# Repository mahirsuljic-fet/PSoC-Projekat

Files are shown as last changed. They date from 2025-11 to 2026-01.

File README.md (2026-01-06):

# PSoC-Projekat

#### [Seminarski rad](https://docs.google.com/document/d/1uanphD6yLatK8Oh72rCpiS6qyERxc_Ud)

## Projekat

### Dokumentacija
- #### [Documentacija projekta](./PSC_gr_6_dokumentacija.pdf)
- #### [Prezentacija projekta](./PSC_gr_6_prezentacija.pptx)

### Kod
- #### [Verilog](./verilog/)
- #### [Mobilna aplikacija](./RobotControlApp/)
- #### [Vcd2plot](./vcd2plot/)

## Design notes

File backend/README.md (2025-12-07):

# Flask backend 
Kako bi Kotlin aplikacija mogla jednostavno komunicirati sa backend-om potrebno je da backend uvijek bude dostupan na istom host-u i istom port-u.

RPi će od momenta boot-anja biti konfigurisan da aktivira svoj hotspot, a android aplikacija se direktno povezuje na tu mrežu.
RPi će imati static IP DHCP konfiguraciju tako da svaki put dobiva istu private IPv4 adresu, npr. 192.168.1.4.
Flask aplikaciji uvijek će biti dodijeljen port 5000.
Tako android aplikacija svaki request šalje na 192.168.1.4:5000/ + odgovarajući endpoint.

## Endpoints
Endpoint-i koje backend expose-a su sljedeći:
 + <code>/forward</code>
   + efektivno postavlja outpin pin na RPi na nivo HIGH, što FPGA dekodira kao kretanje unaprijed
 + <code>/backward</code>
   + efektivno postavlja output pin na RPi na nivo HIGH, što FPGA dekodira kao kretanje unazad
 + <code>/stop</code>
   + efektivno postavlja output pin na RPi na nivo HIGH, što FPGA dekodira kao zaustavljanje kretanja
 + <code>/left</code>
   + efektivno postavlja output pin na RPi na nivo HIGH, što FPGA dekodira kao kretanje lijevo
 + <code>/right</code>
   + efektivno postavlja output pin na RPi na nivo HIGH, što FPGA dekodira kao kretanje desno
 + <code>/</code>
   + index ili root path, ne radi ništa

## Startup
Kako ovaj backend servis treba da radi od samog starta, bit će kreiran sytemd servis koji će prilikom boot-a Raspbian sistema pokrenuti  i ovu Flask aplikaciju.

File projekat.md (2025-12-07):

# Opis projekta
Tema projekta je automobil koji se kontroliše putem mobilne aplikacije.
Automobil će imati 4 točka, 2 kočnice, parking senzore, LED svjetla, sposobnost detektovanja svjetla na semaforu, saobraćajnih znakova, prevenciju prelazka preko linije, itd.
Mobilna aplikacija će biti napisana u Kotlin programskom jeziku koristeći Android Studio i Jetpack Compose.
Komunikacija između mobilne aplikacije i Raspberry Pi će se odvijati putem HTTP protokola.
Komunikacija između Raspberry Pi i FPGA će se odvijati putem nekog serijskog transfer protokola (UART, I2C, SPI ili USB).

# Hardver sa tabelom ulaza i izlaza
| Upravljačke ploče | Slika |
| --- | ----- |
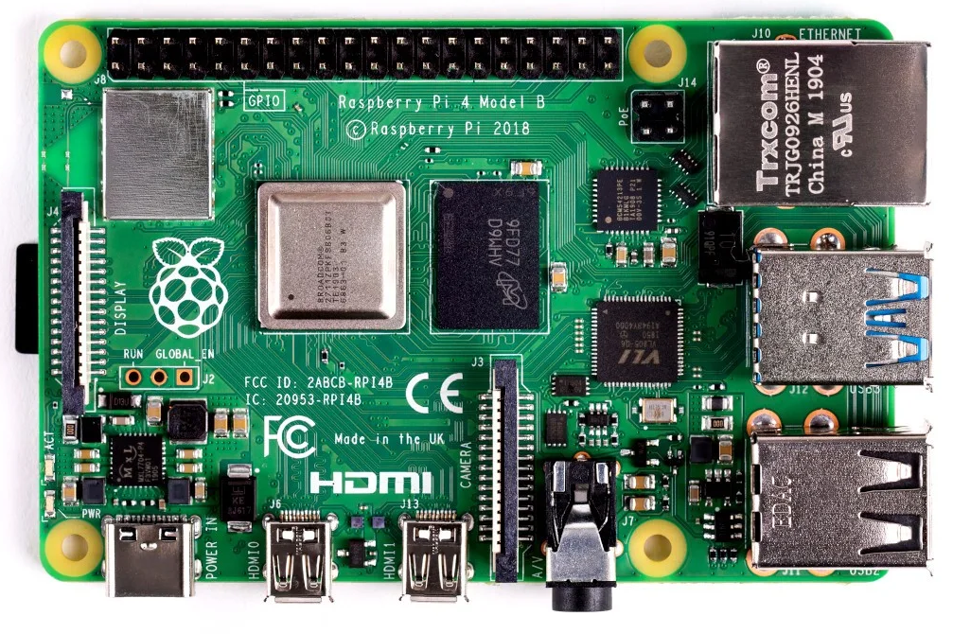
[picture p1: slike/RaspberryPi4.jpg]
| Raspberry Pi 4 |  |
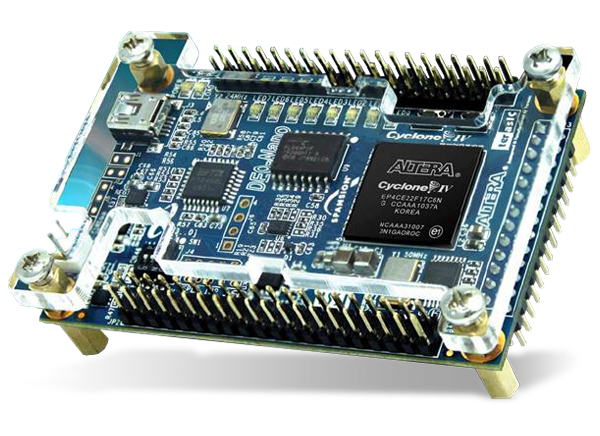
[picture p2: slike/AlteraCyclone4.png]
| Altera Cyclone 4 (FPGA) |  |
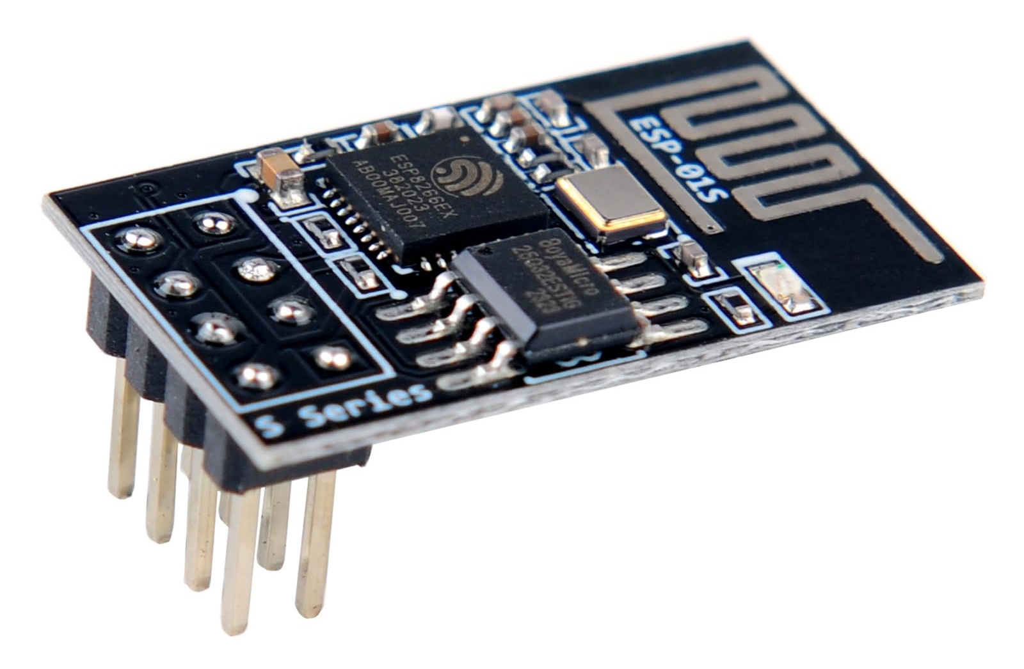
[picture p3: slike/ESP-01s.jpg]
| ESP-01s |  |

| Ulazi | Upravljačka ploča | Namjena | Slika |
| --- | --- | --- | ----- |
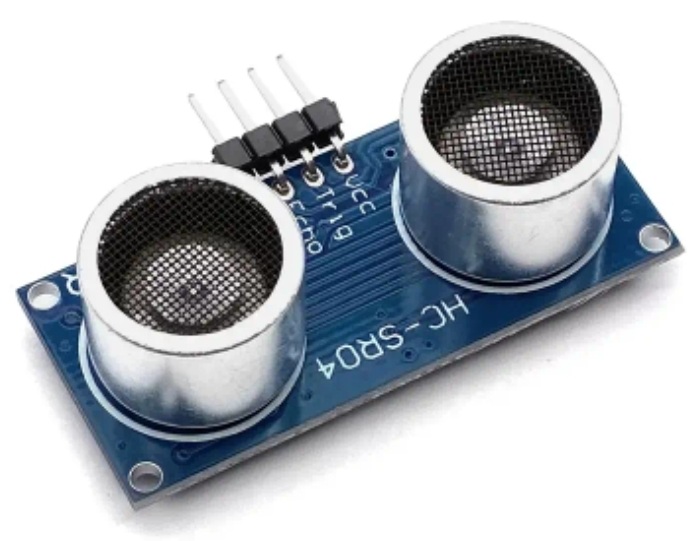
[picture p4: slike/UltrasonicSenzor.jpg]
| Ultrasonični senzor (HC-SR04P) x2 | FPGA | Parking senzori |  |
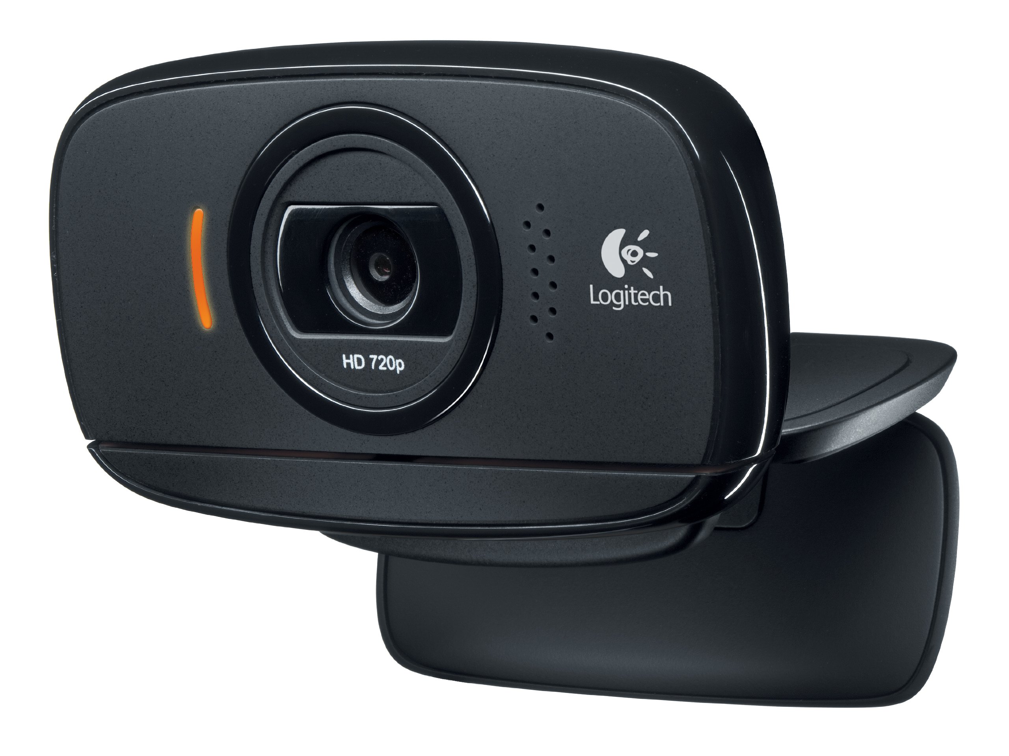
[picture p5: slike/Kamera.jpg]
| Kamera (Logitech C512) | Raspberry PI | Detekcija znakova i video stream |  |
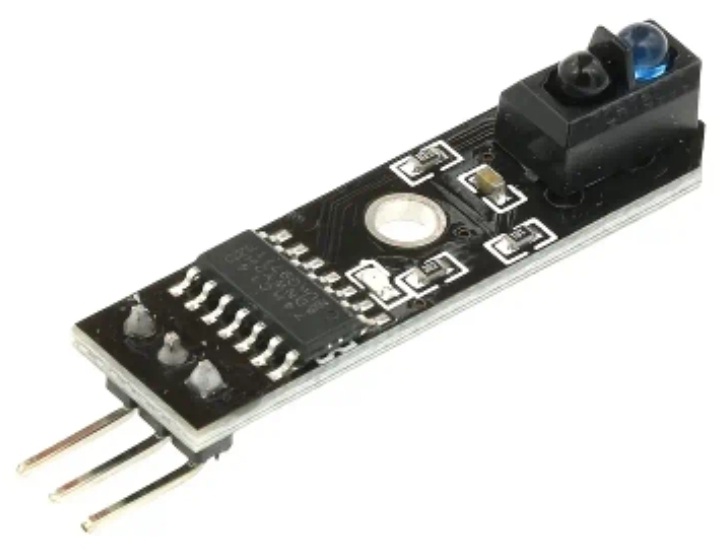
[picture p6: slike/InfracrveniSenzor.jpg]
| Infracrveni senzor x2 | FPGA | Detekcija linija |  |

| Izlazi | Upravljačka ploča | Namjena | Slika |
| --- | --- | --- | ----- |
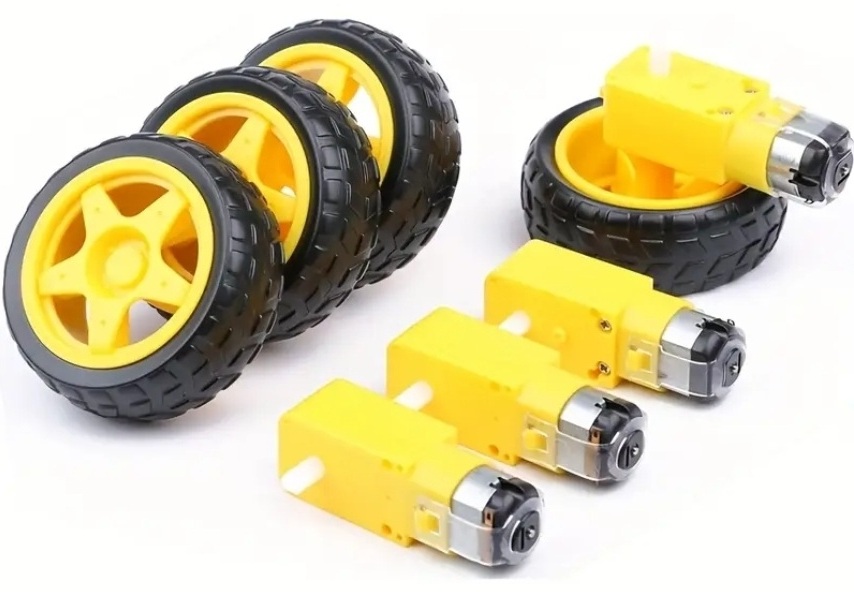
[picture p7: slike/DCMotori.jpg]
| DC motori x4 | FPGA | Kontrola kretanja |  |
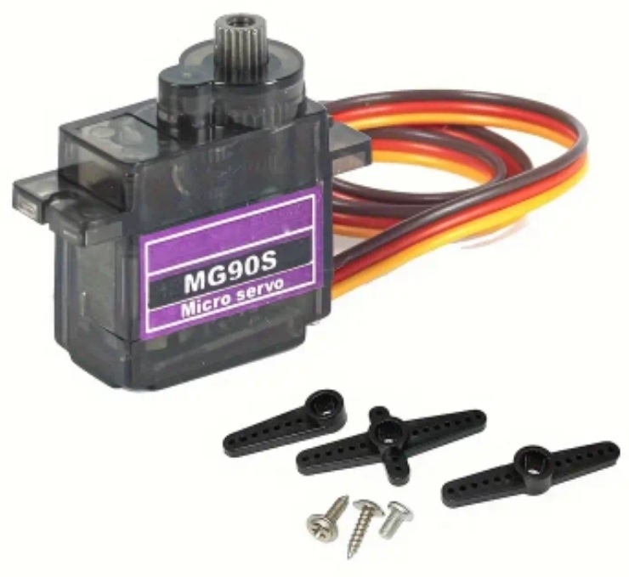
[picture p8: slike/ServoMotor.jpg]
| Servo motori x2 | FPGA | Kočnice |  |
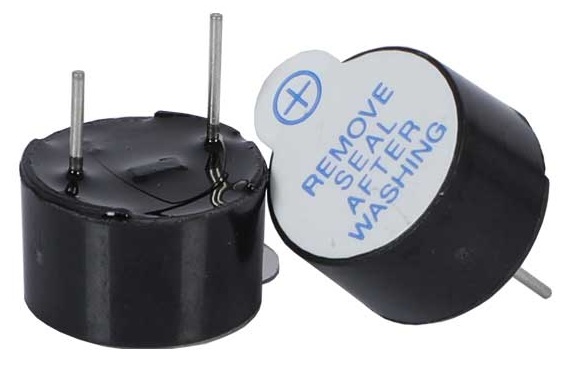
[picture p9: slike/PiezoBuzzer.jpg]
| Aktivni piezo buzzer | FPGA | Zvučna signalizacija |  |
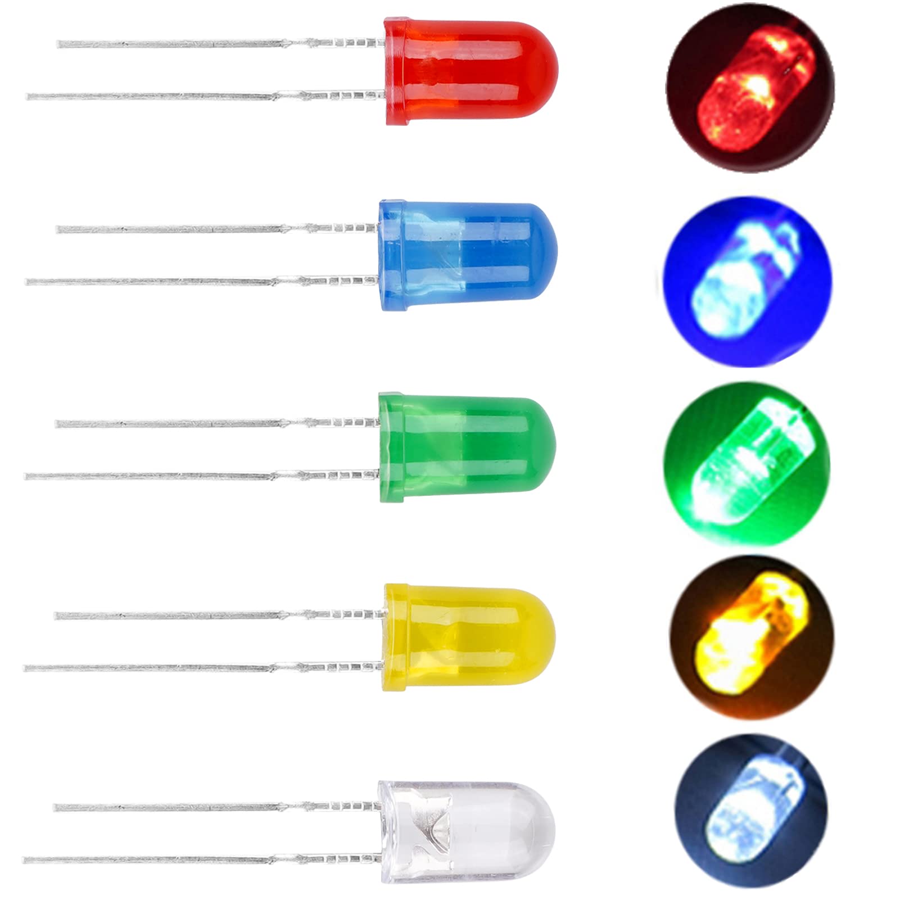
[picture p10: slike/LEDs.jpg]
| LED (nekoliko) | FPGA | Svjetlosna signalizacija |  |

| Dodatno | Upravljačka ploča | Namjena | Slika |
| --- | --- | --- | ----- |
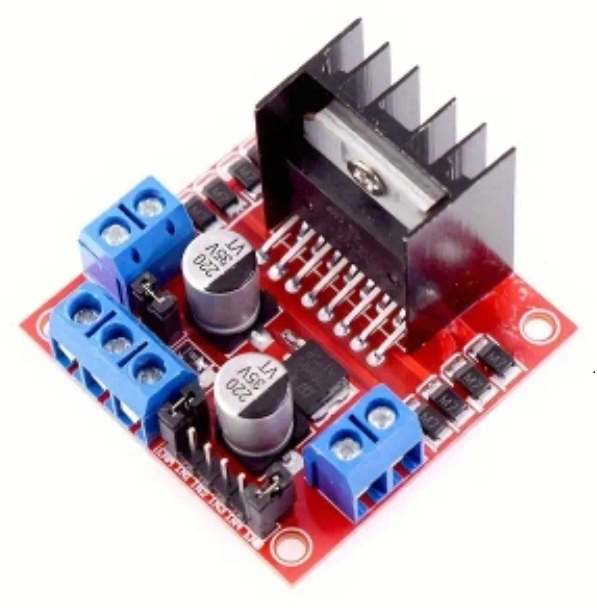
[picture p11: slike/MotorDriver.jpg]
| DC motor driver L298N x2 | FPGA | Kontrola motora |  |
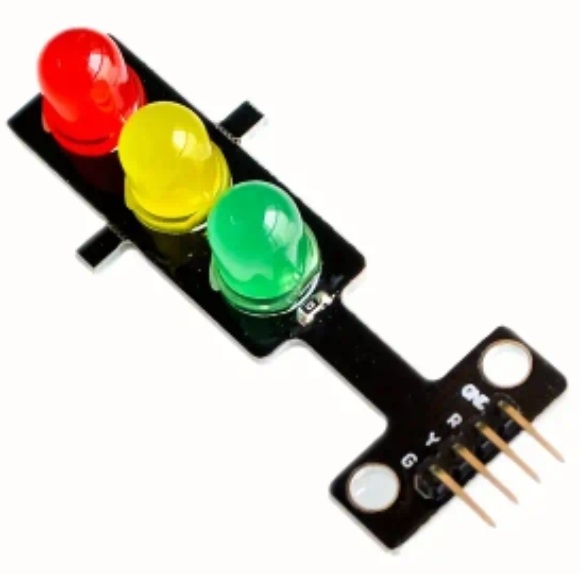
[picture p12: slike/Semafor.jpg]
| LED semafor | ESP-01s | Svjetlosna signalizacija |  |

# Dijagram upravljanja
``` mermaid
%%{init: { "fontFamily": "GitLab Sans" }}%%
flowchart LR
    accTitle: Flowchart

    Camera(Kamera)
    RPi(Raspberry Pi)
    FPGA(Altera Cyclone 4<br>FPGA)
    Driver(DC motor driver)
    Motors(DC motori)
    Inputs(Ultrasonični senzor<br>Infracrveni senzor)
    Outputs(LED<br>Piezo buzzer<br>Servo motori)
    App(Mobilna aplikacija)
    ESP(ESP-01s)
    TL(Semafor)

    App --> RPi
    Camera --> RPi
    RPi --> FPGA
    FPGA --> Driver --> Motors
    Inputs --> FPGA
    FPGA --> Outputs

    ESP --> TL
```

Raspberry Pi će uzimati video stream od kamere i pomoću AI detektovati koje je svjetlo upaljeno na semaforu, kao i STOP znak.
Taj video stream će također slati na mobilnu aplikaciju.
Mobilna aplikacija će slati kontrolne signale (kretanje, kočenje i zvučni signal) na Raspberry Pi koji će dalje te signale proslijediti do FPGA.
FPGA će uzimati i procesirati signale sa Raspberry Pi, ultrasoničnih i infracrvenih senzora, i procesirati ih.
Nakon procesiranja signala će slati kontrole signale ostalim komponentama kao što su LED na autu, piezo buzzer, servo motore i DC motor driver koji će dalje pokretati DC motore na koje su pričvršćeni točkovi.

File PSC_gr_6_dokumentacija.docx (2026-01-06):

Univerzitet u Tuzli Fakultet elektrotehnike Automatika i robotika

Projektovanje sistema na čipu

TEMA: WiFi upravljani mobilni robot sa autonomnim sistemima za sigurnost

Profesorica: Studenti:

dr.sc. Lejla Banjanović – Mehmedović, Amar Kešetović

vanredni prof. Dženana Sadiković

Dženita Moranjkić

Mahir Suljić

Januar, 2026.

SADRŽAJ

1. UVOD 1

2. OPIS PROJEKTNOG ZADATKA 2

2.1. ZADACI PROJEKTA 3

2.2. CILJEVI PROJEKTA 3

2.3. PRIMJENA 4

3. SPECIFIKACIJA MATERIJALA 4

4. OPISI KORIŠTENIH KOMPONENTI 7

4.1. FPGA CYCLONE II 7

4.2. RASPBBERY PI 4 8

4.3. ESP – 01S 9

4.4. ULAZNE KOMPONENTE 10

4.4.1. Ultrasonični senzor HC-SR04P 10

4.4.2. Kamera Logitech C512 10

4.4.3. Infracrveni sensor 11

4.5. IZLAZNE KOMPONENTE 11

4.5.1. DC motor 11

4.5.2. Aktivni piezo buzzer 12

4.6. DC MOTOR DRIVER L298N 12

5. UPRAVLJAČKA LOGIKA I SISTEMSKA INTEGRACIJA 13

5.2. ULAZNI I IZLAZNI SIGNALI ZA FPGA 15

5.3. ULAZNI I IZLAZNI SIGNALI ZA RASPBERRY PI 17

5.4. LOGIKA PRIORITETA KRETANJA 17

5.5. ZVUČNA SIGNALIZACIJA I SENZORI 18

5.6. MEHANIZMI KONTROLE I ZAŠTITE 18

6. 3D MODEL I FINALNI IZGLED PROJEKTA 19

7. MOBILINA ANDROID APLIKACIJA 21

8. KOD 23

8.1. VERILOG KOD ZA KONTROLU DC MOTORA NA FPGA 23

8.2. VERILOG KODA ZA IMPLEMENTACIJU KONTROLE ZVUČNE SIGNALIZACIJE PARKING SENZORA NA FPGA 25

8.3. VERILOG KOD ZA INTEGRCIU SENZORA I MOTORA 26

8.4. KOD NA RASPBERRY PI ZA DETEKCIJU SAOBRAĆAJNIH ZNAKOVA KORIŠTENJEM KAMERE 28

8.5. KOD ZA KOMUNIKACIU IZMEĐU MOBILNE APLIKACIJE I RASPBERRY PI 35

8.6. KOD ZA SIMULACIJU RADA SEMAFORA 39

8.7. KOTLIN KOD ZA ANDROID MOBILNU APLIKACIJU 40

8.7.1. data/models/RobotStatus.kt 40

8.7.2. data/RobotRepository.kt 41

8.7.3. network/RetrofitClient.kt 43

8.7.4. network/RobotApiService.kt 44

8.7.5. ui/components/ActionButton.kt 45

8.7.6. ui/components/ControlPad.kt 46

8.7.7. ui/screens/MainActivity.kt 48

8.7.8. ui/screens/RobotControlScreen.kt 49

8.7.9. viewmodel/RobotViewModel.kt 54

8.7.10. Ostala podešavanja za rad aplikacije 58

REFERENCE 60

POPIS TABELA

Tabela 3.1. - Upravljačke ploče 4

Tabela 3.2. – Ulazne komponente 5

Tabela 3.3. - Dodatne komponente 5

Tabela 3.4. - Izlazne komponente 6

POPIS SLIKA

Slika 1. - Šema povezivanja komponenti sa FPGA i Raspbbery Pi 14

Slika 2. - Lista pinova za FPGA 15

Slika 3. – Raspored pinova za FPGA 16

Slika 4. - 3D model robota izrađen u FreeCAD-u 19

Slika 5. - Finalni izgled projektnog zadatka 20

Slika 6. - Maketa znaka STOP 21

Slika 7. - Model semafora 21

Slika 8. - Glavni upravljački ekran 22

Slika 9. - Prikaz greške u konekciji 23

Slika 10. - Postavke mrežnih parametara 23

# 1. UVOD

Savremeni razvoj transportnih sistema i logistike sve se više oslanja na integraciju autonomnih vozila i pametnih robotskih platformi. Glavni izazovi u ovom domenu obuhvataju postizanje visoke preciznosti u upravljanju, osiguranje maksimalne sigurnosti putem sistema za asistenciju vozaču, te uspostavljanje pouzdane komunikacije u realnom vremenu. Cilj ovog projekta je razvoj WiFi upravljanog mobilnog robota sa autonomnim sistemima za sigurnost, koji kombinuje fleksibilnost ručnog upravljanja putem mobilne aplikacije sa naprednim funkcijama automatske prevencije nezgoda.

Sistem je zasnovan na sinergiji Raspberry Pi platforme, koja vrši obradu slike i AI detekciju saobraćajne signalizacije, te FPGA kontrolera, koji osigurava determinističko upravljanje motorima i obradu senzorskih podataka u realnom vremenu. Ovakva arhitektura omogućava implementaciju kompleksnih funkcija poput detekcije linija, automatskog kočenja pri prepoznavanju "STOP" znaka ili crvenog svjetla na semaforu, te inteligentnog sistema za parkiranje.

Primjena ovakvog sistema nudi širok spektar mogućnosti, od edukacijskih platformi za testiranje algoritama autonomne vožnje do primjene u pametnim skladištima gdje je potrebna visoka sigurnost pri kretanju. Integracija senzora za blizinu, infracrvenih senzora za praćenje trake i vizuelne povratne informacije putem (near) real-time video streama, direktno doprinosi minimizaciji ljudske greške i povećanju operativne sigurnosti.

Kroz realizaciju ovog projekta, demonstrira se kako se moderni komunikacioni protokoli, vještačka inteligencija i namjenska hardverska arhitektura mogu ujediniti u jedinstven, skalabilan sistem. Ovakva rješenja predstavljaju ključni korak ka modernizaciji transporta i razvoja inteligentnih mašina sposobnih da autonomno reaguju na nepredviđene situacije u okruženju, čime se postavljaju novi standardi u sigurnosti i efikasnosti mobilnih robotskih sistema.

# 2. OPIS PROJEKTNOG ZADATKA

Tema projekta je automobil koji se kontroliše putem mobilne aplikacije. Automobil posjeduje 4 točka, kameru, parking senzore, zvučnu signalizaciju, LED svjetla, te sposobnost detektovanja svjetla na semaforu, saobraćajnih znakova i prevenciju prelazka preko linije.

Komunikacija između Raspberry Pi i FPGA ploče odvija se putem digitalnih pinova. Svaki pin je zadužen za jednu od sljedećih akcija: kretanje naprijed, kretanje nazad, kretanje desno, kretanje lijevo, zvučni signal.

Mobilna aplikacija je napisana u Kotlin programskom jeziku koristeći Android Studio i Jetpack Compose. Kamera se nalazi na prednjoj strani automobila, a aplikacija omogućava (near) real-time prikaz onoga što kamera automobila vidi. Na jednoj strani ekrana nalaze se komande za kretanje automobila, dok je na drugoj strani komanda za zvučnu signalizaciju. Komunikacija između mobilne aplikacije i Raspberry Pi mikroračunara odvija se putem HTTP protokola.

FPGA preko drivera za motore (H-mosta) kontroliše motore pričvršćene na točkove. Jedan driver može pokretati dva motora, pa su u sistem integrisana dva drivera – jedan za lijevi i jedan za desni par točkova. Ovakav raspored omogućava korištenje diferencijalnog upravljanja, gdje se za skretanje udesno snaga lijevom paru točkova povećava, a desnom smanjuje, i analogno za skretanje ulijevo.

Kada kamera detektuje crveno svjetlo na semaforu ili znak stop, Raspberry Pi automatski šalje signal za kočenje. Ako ultrazvučni senzori detektuju približavanje prepreci, FPGA pomoću aktivnog piezo buzzera generiše zvuk, slično parking senzorima u automobile. Sa strana automobila nalaze se infracrveni senzori za detekciju linija. Ako senzor detektuje liniju, šalje se signal za blago skretanje u suprotnom smjeru kako bi se vozilo vratilo unutar linija.

Odvojeno od glavnog projekta realizovan je semafor. Semafor se sastoji od tri LED (crvena, žuta i zelena) koje kontroliše ESP-01S. Sistem simulira ponašanje pravog semafora sa smjenama crvenog, žutog i zelenog svjetla.

## 2.1. ZADACI PROJEKTA

Za uspjesnu realizaciju projekta potrebno je ispuniti sljedeće zadatke:

1. Programiranje PFGA kontrolera
- Implementacija modula za precizno upravljanje motorima.
- Razvoj logike za obradu signala sa ultrazvučnih senzora (parking senzori) i infracrvenih senzora (praćenje linije).
- Logička kontrola svjetlosne i zvučne signalizacije (LED i buzzer).
2. Programiranje na Raspberry Pi platformi
- Implementacija HTTP servera u Pythonu za potrebe mrežne komunikacije i razmjene podataka sa kontrolnom aplikacijom.
- Razvoj AI detektora za prepoznavanje boja na semaforu i "Stop" znakova koristeći kameru.
3. Razvoj kontrolne android aplikacije
- Izrada korisničkog interfejsa u Kotlinu koji omogućava upravljanje robotom.
4. Realizacija eksternog semafora
- Programiranje ESP-01S modula za kontrolu LED dioda koje simuliraju rad pravog semafora.
5. Hardverska realizacija vozila
- Sklapanje vozila sa četiri točka i integracija DC motora sa H-most driverima.
- Povezivanje Raspberry Pi mikroračunara i FPGA ploče putem GPIO pinova za potrebe komunikacije.
- Povezivanje senzorskog sistema (ultrazvučni, infracrveni i kamera).
6. Izrada makete

## 2.2. CILJEVI PROJEKTA

Glavni cilj projekta je dizajn i implementacija mobilnog robota koji kombinuje daljinsko upravljanje putem WiFi mreže i autonomne sigurnosne sisteme. Fokus je na korištenju Raspberry Pi i FPGA kako bi se postigao visok stepen pouzdanosti. Specifični ciljevi uključuju:

- Povećanje sigurnosti: Implementacija sistema koji procesiranjem informacija sa senzora i kamere sprječava vozača da namjerno ili nenamjerno ošteti robota ili načini neku vrstu prekršaja.
- Istraživanje mašinskog učenja: Primjena AI modela za prepoznavanje vizuelnih simbola u realnom vremenu.
- Determinizam upravljanja: Korištenje FPGA za trenutnu reakciju na prepreke i korekciju putanje, čime se eliminišu kašnjenja softvera.

## 2.3. PRIMJENA

Projektni sistem ima širok potencijal primjene u modernim industrijama:

- Autonomna transportna vozila: U pametnim fabrikama i skladištima za siguran prevoz robe uz poštovanje interne signalizacije.
- Sistemi asistencije vozaču: Prototip rješenja za prevenciju sudara i automatsko kočenje u putničkim vozilima.
- Edukacija i istraživanje: Platforma za testiranje algoritama autonomnog kretanja i proučavanje komunikacije između različitih hardverskih nivoa.
- Rad u opasnim okruženjima: Daljinski upravljana vozila sa ugrađenim "instinktima" za samoočuvanje u slučaju gubitka veze sa operaterom.

# 3. SPECIFIKACIJA MATERIJALA

Upravljačke ploča | Slika

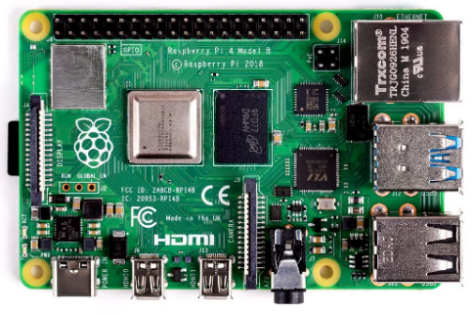
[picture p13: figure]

Raspberry Pi 4

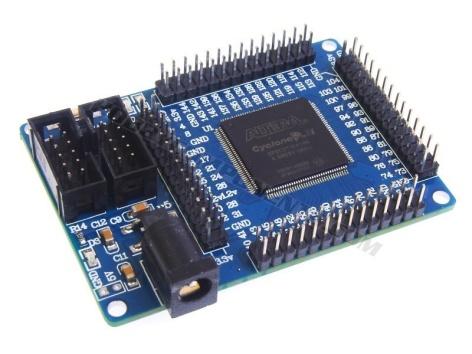
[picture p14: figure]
Altera Cyclone II ES2C5T144 FPGA Dev Board

Altera Cyclone 2 (FPGA)

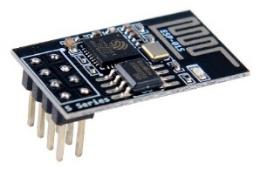
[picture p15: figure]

ESP-01S

Tabela 3.1. - Upravljačke ploče

Ulazi | Upravljačka ploča | Namjena | Slika

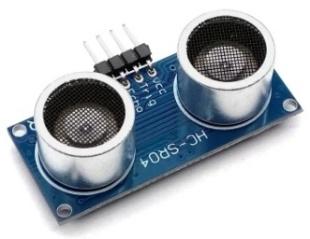
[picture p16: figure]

Ultrasonični senzor (HC-SR04P) x2 | FPGA | Detekcija prepreka

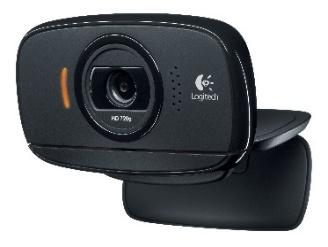
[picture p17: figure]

Kamera (Logitech C512) | Raspberry PI | Detekcija znakova i video stream

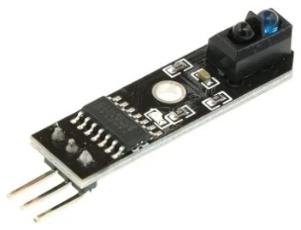
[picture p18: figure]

Infracrveni senzor x2 | FPGA | Detekcija linija

Tabela 3.2. – Ulazne komponente

Dodatno | Upravljačka ploča | Namjena | Slika

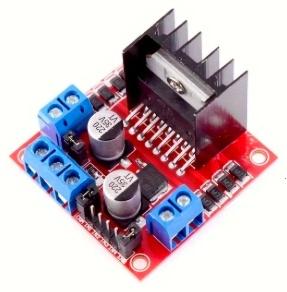
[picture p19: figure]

DC motor driver L298N x2 | FPGA | Kontrola motora

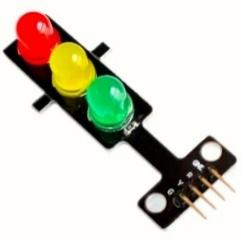
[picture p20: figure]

LED semafor | ESP-01S | Svjetlosna signalizacija

Tabela 3.3. - Dodatne komponente

Izlazi | Upravljačka ploča | Namjena | Slika

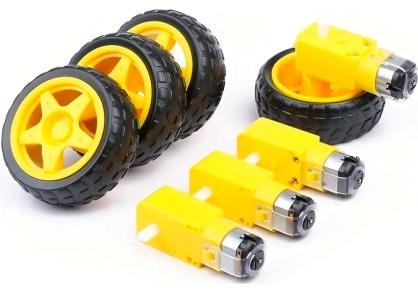
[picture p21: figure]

DC motori x4 | FPGA | Kontrola kretanja

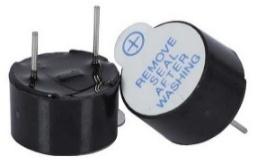
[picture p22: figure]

Aktivni piezo buzzer | FPGA | Zvučna singnalizacija

Tabela 3.4. - Izlazne komponente

# 4. OPISI KORIŠTENIH KOMPONENTI

## 4.1. FPGA CYCLONE II

FPGA (Field-Programmable Gate Array) je integrisano kolo koje korisnici mogu programirati nakon proizvodnje da bi realizovali specifične digitalne logičke funkcije. Cyclone II je serija FPGA uređaja razvijena od strane kompanije Intel (nekadašnja Altera), dizajnirana da pruži visoku gustinu logike po niskoj cijeni. Za razliku od procesora sa fiksnim instrukcijama, ovaj uređaj omogućava hardversku implementaciju specifičnih digitalnih funkcija putem konfigurabilnih logičkih blokova, optimizovanih za aplikacije gdje su bitni troškovi proizvodnje.

Arhitekturu Cyclone II čipa čine sljedeći ključni podsistemi:

- Logički elementi (LE): Predstavljaju osnovne jedinice za obradu. Svaki LE sadrži četvoroulaznu tabelu pretraživanja (LUT), programabilni registar i prenosni lanac (carry chain) za brze aritmetičke operacije. Ovi elementi su organizovani u Logic Array Blocks (LAB), koji omogućavaju efikasno grupisanje logike i lokalno rutiranje signala.
- Memorijski resursi (Embedded Memory): Interna memorija je realizovana kroz M4K blokove. Svaki blok ima kapacitet od 4 kilobita i može se konfigurisati kao RAM, ROM ili FIFO memorija. Ovi blokovi podržavaju rad u režimu istovremenog čitanja i pisanja (dual-port RAM) i rade na frekvencijama do 250 MHz.
- Namjenski množitelji (Embedded Multipliers): Za razliku od novijih DSP blokova, Cyclone II posjeduje namjenske hardverske množitelje (18x18 bitova). Oni su optimizovani za operacije množenja koje su osnova digitalne obrade signala, čime se štede logički resursi koji bi inače bili utrošeni na softversku implementaciju množenja.
- Ulazno-izlazni elementi (IOEs): Podržavaju brojne I/O standarde (kao što su LVTTL, LVCMOS, SSTL) i diferencijalne signale (LVDS). Svaki IOE sadrži bidirekcioni bafer i registre koji omogućavaju precizno tempiranje signala na pinovima čipa.
- Sistem povezivanja (Interconnect): Koristi se MultiTrack struktura usmjeravanja. To je mreža bakarnih linija različitih dužina koje omogućavaju povezivanje logičkih blokova uz predvidljivo i minimalno kašnjenje signala (propagation delay).
- Konfiguracija: Arhitektura je bazirana na SRAM tehnologiji, što znači da je konfiguracija volatilna i gubi se nakon isključenja napajanja. Čip se konfiguriše prilikom svakog pokretanja (power-up) putem eksternih konfiguracionih memorija (poput EPCS serije) ili direktno putem JTAG interfejsa.

## 4.2. RASPBBERY PI 4

Raspberry Pi je računar na jednoj ploči (SBC) zasnovan na ARM arhitekturi. On integriše procesor, memoriju, grafiku i ulazno/izlazne portove na jednoj štampanoj ploči (PCB). Zbog svoje robusnosti i malih dimenzija, koristi se za IoT aplikacije, robotiku i obradu podataka u stvarnom vremenu.

Hardverske komponente

- Procesor (CPU): Četverojezgreni procesor (1.5 GHz) koji služi kao „mozak“ uređaja za obradu podataka.
- Grafički procesor (GPU): Broadcom VideoCore, omogućava 3D renderovanje i 4K prikaz na dva monitora.
- Memorija i skladištenje: Koristi MicroSD karticu za operativni sistem i pohranu podataka.
- Mrežna povezanost: Gigabit Ethernet za žičanu mrežu, uz ugrađeni Wi-Fi i Bluetooth (BLE).
- GPIO pinovi: 40 pinova za direktno upravljanje eksternim hardverom (senzori, motori, LED).

Interfejsi i konekcija

- HDMI: Prenos slike i zvuka visoke definicije.
- CSI (Camera Serial Interface): Namjenski port za povezivanje kamera.
- DSI (Display Serial Interface): 15-pinski konektor za LCD ekrane.
- UART: Protokol za serijsku komunikaciju sa drugim mikrokontrolerima ili modulima.
- USB portovi: Za povezivanje periferije (tastature, miševi, eksterni diskovi).
- Napajanje: USB-C konektor (kod novijih modela) za dovod električne energije.

Modeli i indikatori

- Model A vs. Model B: Model A je energetski efikasniji i nema Ethernet port, dok je Model B snažniji i opremljen mrežnim portom.
- Statusne LED diode:
  - Crvena (PWR): Indikator stabilnog napajanja.
  - Zelena (ACT): Indikator aktivnosti čitanja/pisanja na SD kartici.

## 4.3. ESP – 01S

ESP-01S je ultra-kompaktni Wi-Fi modul zasnovan na ESP8266 mikrokontroleru. Dizajniran je da omogući uređajima pristup internetu ili da služi kao samostalni kontroler za jednostavne IoT projekte. Predstavlja unapređenu verziju originalnog ESP-01 modula, sa boljim performansama antene i optimizovanim hardverom.

Hardverske komponente

- Procesor (CPU): L106 32-bitni RISC mikroprocesor sa radnim taktom od 80 MHz (može se povećati do 160 MHz).
- Memorija (Flash): Najčešće dolazi sa 1 MB flash memorije za skladištenje koda i podataka.
- Wi-Fi modul: Podržava 802.11 b/g/n standarde, omogućavajući Wi-Fi Direct (P2P) i soft-AP režime.
- Integrisana antena: Posjeduje PCB antenu „na ploči“, što eliminiše potrebu za vanjskim dodacima za osnovnu komunikaciju.

Pinovi i povezivanje

ESP-01S ima 8 pinova raspoređenih u 2x4 zaglavlje:

- VCC: Napajanje od tačno 3.3V (nije tolerantan na 5V).
- GND: Uzemljenje.
- TX/RX: Pinovi za serijsku komunikaciju (UART) za programiranje i slanje podataka.
- GPIO 0 i GPIO 2: Digitalni ulazno/izlazni pinovi (GPIO 0 se koristi i za ulazak u mod za programiranje).
- CH_PD (EN): Pin za omogućavanje čipa; mora biti spojen na visoki napon (3.3V) da bi modul radio.
- RST: Reset pin.

Ključne karakteristike i prednosti

- Mala potrošnja energije: Dizajniran za mobilne i baterijske uređaje; posjeduje "deep sleep" mod.
- Samostalni rad: Može se koristiti kao most za Arduino (preko AT komandi) ili se programirati direktno putem Arduino IDE ili MicroPython-a.
- Kompaktnost: Zahvaljujući malim dimenzijama, idealan je za ugradnju u pametne prekidače, senzore temperature i druge male uređaje.
- Unapređenja (u odnosu na ESP-01): Bolji dizajn štampane ploče i izbačeni nepotrebni otpornici, što olakšava direktno povezivanje.

## 4.4. ULAZNE KOMPONENTE

### 4.4.1. Ultrasonični senzor HC-SR04P

Ultrasonični senzor HC-SR04 je elektronski uređaj koji mjeri udaljenost do objekta emitovanjem ultrazvučnih talasa i pretvaranjem reflektovanog zvuka u električni signal. Sastoji se od dvije glavne komponente: odašiljača, koji emituje zvuk pomoću piezoelektričnih kristala, i prijemnika, koji registruje povratni talas. Udaljenost D se izračunava mjerenjem vremena T potrebnog da talas ode do cilja i vrati se nazad, koristeći brzinu zvuka C. Ovi senzori su otporniji na smetnje izazvane dimom i gasovima u odnosu na infracrvene senzore, a primjenjuju se u sistemima za parkiranje, robotici i detekciji prepreka. Senzor radi na naponu od 5V DC uz radnu struju od 15mA. Njegov radni frekvencijski opseg je 40kHz. Minimalni domet mjerenja iznosi 2 cm, dok je maksimalni domet do 400 cm. Preciznost mjerenja (tačnost) je 3 mm, a senzor pokriva ugao manji od 15°. Dimenzije samog uređaja su 45 x 20 x 15 mm.

Raspored pinova:

- Vcc: Napajanje (+5V).
- Trigger: Pin koji inicira slanje ultrazvučnog impulsa.
- Echo: Pin koji šalje signal proporcionalan trajanju povratka talasa.
- GND: Uzemljenje.

### 4.4.2. Kamera Logitech C512

Logitech C512 je kompaktna, prenosiva HD web kamera dizajnirana za video pozive i snimanje u visokoj rezoluciji. Koristi stakleni objektiv i tehnologiju autofokusa kako bi osigurala oštru sliku čak i u krupnom planu, dok ugrađeni mikrofon sa redukcijom šuma omogućava jasan prenos glasa bez pozadinske buke. Zahvaljujući "fold-and-go" dizajnu, kamera se lako sklapa i štiti objektiv tokom transporta, što je čini idealnom za korisnike u pokretu. Povezuje se putem standardnog USB interfejsa (Plug-and-Play) i automatski korigira osvjetljenje kako bi pružila kvalitetan video u različitim uslovima ambijentalnog svjetla.

Tehničke specifikacije i povezivanje

- Maksimalna rezolucija: 720p HD video pozivi i snimanje.
- Fokus: Napredni sistem autofokusa.
- Mikrofon: Ugrađen sa tehnologijom za suzbijanje buke.
- Povezivanje: USB 2.0 (standardni tip A).
- Dizajn: Rotacija od 360 stepeni i sklopiva konstrukcija.

### 4.4.3. Infracrveni sensor

Infracrveni senzor je elektronski uređaj koji detektuje prisustvo objekata ili mjeri toplotu emitovanjem ili primanjem infracrvenog zračenja. Najčešće se koristi kao senzor blizine koji radi na principu refleksije: IR dioda (predajnik) emituje svjetlost nevidljivu ljudskom oku, a ukoliko se ispred senzora nađe objekat, svjetlost se odbija nazad do fotodiode (prijemnika). Za razliku od ultrasoničnih senzora, infracrveni senzori su brži u detekciji, ali mogu biti osjetljivi na ambijentalno svjetlo i boju objekta (npr. crne površine apsorbuju IR zrake, što otežava detekciju).

Tehničke karakteristike i povezivanje

- Radni napon: Tipično 3.3V do 5V DC.
- Domet detekcije: Podesiv putem potenciometra (obično od 2 cm do 30 cm).
- Ugao detekcije: Oko 35°.
- Izlazni signal: Digitalni (0 ili 1) – logička nula kod detekcije prepreke.

Opis pinova

- VCC: Pozitivno napajanje (3.3V - 5V).
- GND: Uzemljenje.
- OUT: Digitalni izlazni signal koji se povezuje na mikrokontroler.

## 4.5. IZLAZNE KOMPONENTE

### 4.5.1. DC motor

DC motor je elektromehanički uređaj koji pretvara jednosmjernu električnu energiju u mehaničku rotaciju. U projektima sa mikrokontrolerima, DC motori se koriste za pokretanje točkova, propelera ili drugih mehanizama. S obzirom na to da motori troše više struje nego što mikrokontroler može pružiti, oni se obično povezuju preko H-mosta ili tranzistora koji omogućavaju kontrolu brzine (pomoću PWM signala) i smjera rotacije.

Tehničke karakteristike i povezivanje:

- Radni napon: Najčešće 3V do 12V DC (zavisno od modela).
- Struja: Zahtijeva eksterne drajvere (npr. L298N) zbog velike startne struje.
- Brzina: Definisana u RPM (broj okretaja u minuti).
- Povezivanje: Posjeduje dva terminala; zamjena polariteta mijenja smjer okretanja.

### 4.5.2. Aktivni piezo buzzer

Aktivni piezo buzzer je zvučni indikator koji generiše ton fiksne frekvencije čim se na njega dovede napon. Za razliku od pasivnog buzzera, aktivni ima ugrađeno oscilatorno kolo, pa mu nije potreban kompleksan signal (PWM) za proizvodnju zvuka, već samo običan digitalni signal (High/Low). Idealni su za alarme, potvrde pritiska tastera i sistemska upozorenja.

Tehničke karakteristike i povezivanje:

- Radni napon: Obično 3.3V do 5V DC.
- Frekvencija: Fiksna, najčešće oko 2.3 kHz.
- Potrošnja: Veoma niska, obično ispod 30mA.
- Povezivanje: Posjeduje duži pin (anoda/+) koji ide na digitalni izlaz i kraći pin (katoda/-) koji ide na uzemljenje (GND).

## 4.6. DC MOTOR DRIVER L298N

L298N je modul zasnovan na dvostrukom H-mostu koji omogućava istovremenu kontrolu brzine i smjera rotacije dva DC motora ili jednog koračnog (stepper) motora. On služi kao posrednik između mikrokontrolera (poput Raspberry Pi ili Arduina) i motora, jer mikrokontroleri ne mogu isporučiti dovoljno struje za pokretanje motora. Modul posjeduje ugrađeni regulator napona od 5V, koji se može koristiti za napajanje same kontrolne logike ili vanjskih komponenti, pod uslovom da je ulazni napon motora veći od 7V.

Tehničke specifikacije

- Radni napon (logika): 5V DC.
- Napon za motore (Drive voltage): 5V do 35V DC.
- Maksimalna struja po kanalu: 2A (vršno do 3A).
- Maksimalna snaga: 25W.
- Broj kanala: 2 (omogućava kontrolu dva nezavisna DC motora).
- Dodatne funkcije: Zaštita od pregrijavanja i ugrađene diode za zaštitu od povratnog napona.

Opis pinova i povezivanje

Modul je podijeljen na tri glavna dijela za povezivanje:

1. Terminali za napajanje
  - VCC: Ulaz za napajanje motora (npr. 12V).
  - GND: Zajedničko uzemljenje za motor i mikrokontroler.
  - 5V: Izlazni/ulazni pin (daje 5V ako je aktivan interni regulator).
2. Izlazi za motore (A i B)
  - OUT1 i OUT2: Priključci za prvi motor.
  - OUT3 i OUT4: Priključci za drugi motor.
3. Kontrolni pinovi (Logika)
  - ENA i ENB: Pinovi za omogućavanje motora (koriste se za kontrolu brzine putem PWM-a).
  - IN1, IN2, IN3, IN4: Digitalni ulazi koji određuju smjer okretanja (npr. IN1 High / IN2 Low okreće motor naprijed).

# 5. UPRAVLJAČKA LOGIKA I SISTEMSKA INTEGRACIJA

Upravljanje sistemom podijeljeno je između Raspberry Pi 4 računara i Altera Cyclone II FPGA čipa. Raspberry Pi 4 služi za procesiranje slike putem OpenCV biblioteke i upravljanje mrežnim saobraćajem preko Flask servera. FPGA vrši obradu signala sa senzora u realnom vremenu, upravlja radom motora i mehanizam kontrole.

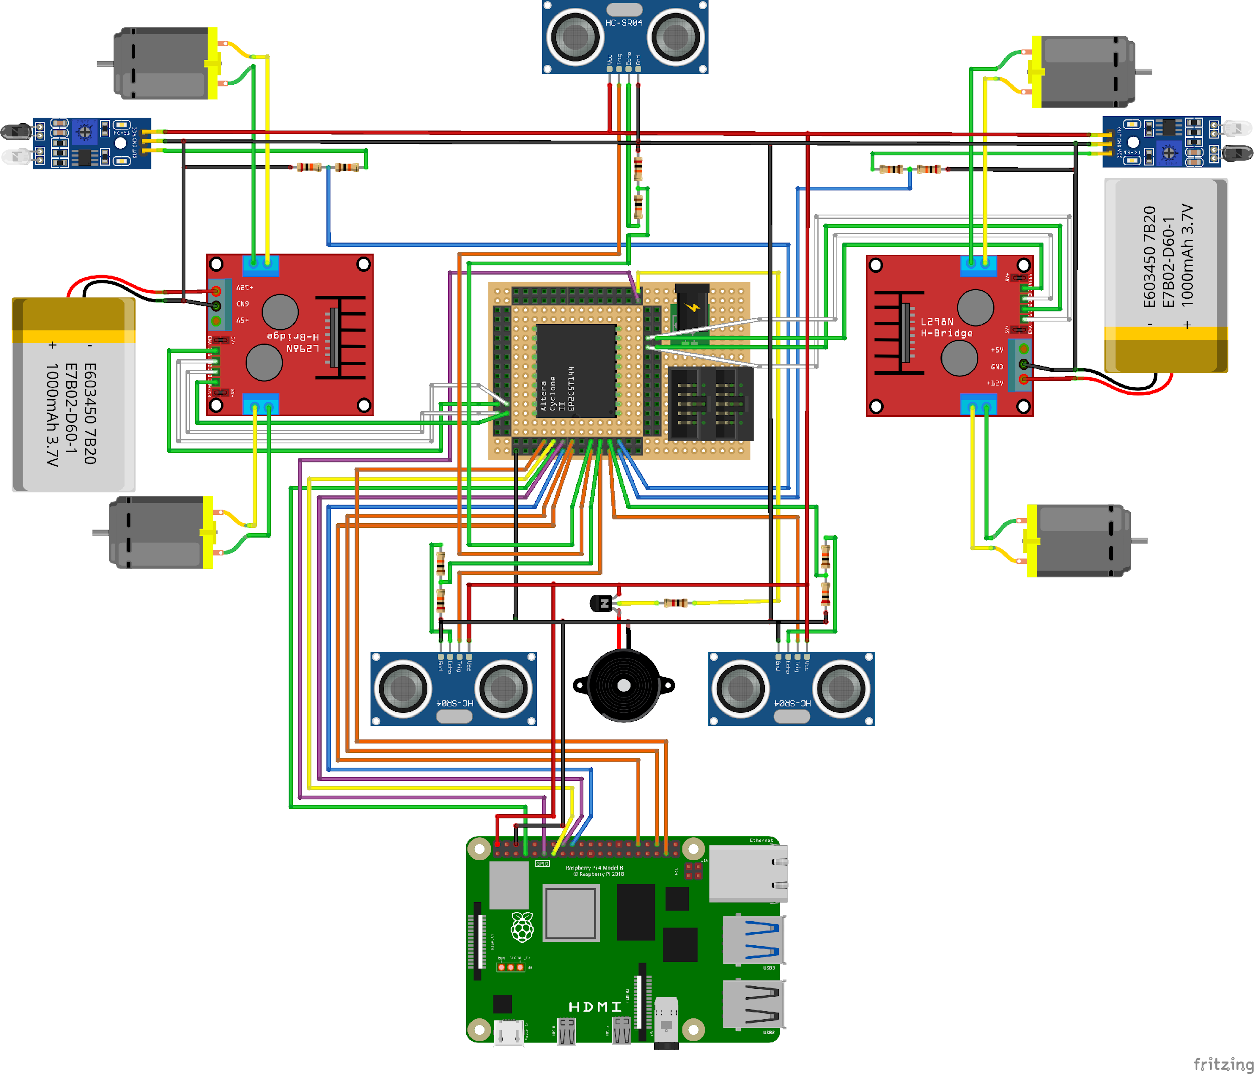
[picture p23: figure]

Slika 1. - Šema povezivanja komponenti sa FPGA i Raspbbery Pi

## 5.2. ULAZNI I IZLAZNI SIGNALI ZA FPGA

Ulazni signali

- Raspberry Pi (GPIO): Prima 7 digitalnih signala koji definišu kretanje (fwd_in, bwd_in, left_in, right_in), detekciju saobraćajnih znakova (stopsign_in, stoplight_in) i sigurnosni prekid (failsafe_in).
- Infracrveni (IR) senzori: Dva digitalna ulaza (ld_left, ld_right) koji šalju logičku jedinicu pri detekciji linije.
- Ultrazvučni senzori (HC-SR04): Tri echo signala koji prenose informaciju o udaljenosti od prepreke.
- Aplikacija: buzzer_in signal za manuelno aktiviranje sirene.

Izlazni signali

- Motor drajveri (L298N): Dva porta sa po 4 bita (m1_out, m2_out) koji kontrolišu smjer i rad četiri elektromotora.
- Ultrazvučni senzori: Tri trig signala za inicijalizaciju mjerenja.
- Zvučna signalizacija: Jedan izlazni pin za kontrolu buzzera.

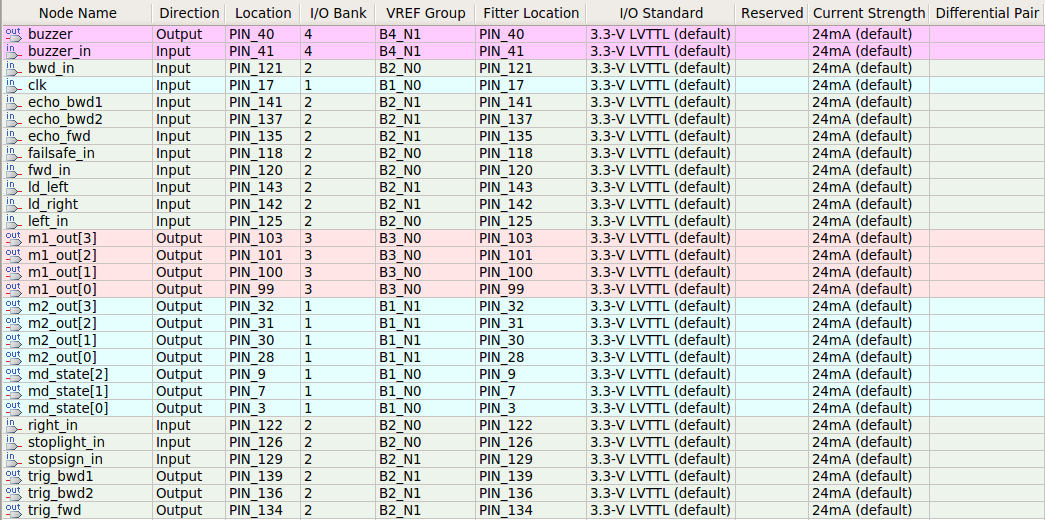
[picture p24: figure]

Slika 2. - Lista pinova za FPGA


Slika 3. – Raspored pinova za FPGA

## 5.3. ULAZNI I IZLAZNI SIGNALI ZA RASPBERRY PI

Raspberry Pi 4 obrađuje podatke sa kamere i upravlja komunikacijom sa korisničkom aplikacijom. On pretvara vizuelne informacije i mrežne komande u digitalne signale koje FPGA može razumjeti.

Ulazni signali

- Kamera: Video signal koji ulazi preko CSI interfejsa (poseban utor na ploči za kameru). OpenCV biblioteka analizira ove slike kako bi prepoznala STOP znak i crveno svjetlo na semaforu.
- Mrežni saobraćaj (Wi-Fi): HTTP zahtjevi koji pristižu na Flask server, sadrže komande za smjer kretanja i "heartbeat" potvrdu od mobilne aplikacije.

Izlazni signali

- Upravljački GPIO pinovi: Sedam digitalnih izlaza koji su direktno povezani na ulaze FPGA čipa (GPIO 4, 27, 23, 24, 16, 12 i 26). Ovi signali prenose komande kretanja, signale detekcije objekata i stanje sigurnosne veze (failsafe).
- Statusni odgovor: HTTP odgovor koji se šalje nazad aplikaciji kao informacija o tome da li se robot trenutno kreće.

## 5.4. LOGIKA PRIORITETA KRETANJA

Unutar FPGA modula za upravljanje motorima (motor_driver) implementirana je stroga hijerarhija signala. Ovo osigurava da robot reaguje ispravno u situacijama kada se pojavi više komandi istovremeno.

Redoslijed prioriteta je sljedeći:

1. Potpuno zaustavljanje: Ako su aktivni signali za gubitak veze, crveno svjetlo na semaforu ili STOP znak, svi ostali ulazi se ignorišu i motori se gase.
2. Praćenje putanje: Ukoliko nema signala za zaustavljanje, a robot se kreće naprijed, prioritet preuzimaju infracrveni senzori. Ako lijevi senzor detektuje liniju, robot automatski skreće udesno, a ako desni detektuje, skreće ulijevo.
3. Korisničko upravljanje: Tek kada su ispunjeni svi sigurnosni uslovi i nema detekcije linija, FPGA izvršava komande kretanja poslane sa Raspberry Pi uređaja.

## 5.5. ZVUČNA SIGNALIZACIJA I SENZORI

Sistem koristi zvučnu signalizaciju kao metodu upozorenja na prepreke. Ova logika je odvojena od modula za motore kako bi radila neovisno i bez kašnjenja.

Tri ultrazvučna senzora (prednji i dva zadnja) šalju podatke FPGA čipu. Unutar modula parking_sensor, trajanje povratnog zvučnog talasa se preračunava u udaljenost. Na osnovu te udaljenosti, FPGA kontroliše zvučnik (buzzer):

- Ako je prepreka blizu (između 15 cm i 20 cm), zvučnik pišti sporije.
- Kako se prepreka približava (između 10 cm i 15 cm), pištanje postaje brže.
- Na udaljenosti manjoj od 10 cm, zvuk postaje konstantan.

Finalni signal za zvučnik dobija se sabiranjem (logička OR operacija) signala sa sva tri senzora i signala svirene sa aplikacije. To znači da će se zvučnik aktivirati ako bilo koji senzor osjeti blizinu ili ako korisnik manuelno pritisne svirenu u kontrolnom interfejsu.

## 5.6. MEHANIZMI KONTROLE I ZAŠTITE

Ovaj dio sistema osigurava da robot ne ostane u pokretu ako nastane problem u komunikaciji ili softveru. Glavni mehanizam je "heartbeat" provjera. Ako aplikacija prestane slati potvrdu u roku od 300 ms (npr. zbog gubitka Wi-Fi signala), Raspberry Pi postavlja failsafe signal na nulu. FPGA to odmah prepoznaje i momentalno isključuje napajanje motora.

Dodatno, kod detekcije STOP znaka, softver putem stopsign_in pina blokira kretanje na tačno 3 sekunde. Tokom ovog perioda, FPGA drži motore u zakočenom stanju, čime se simulira obavezno zaustavljanje u saobraćaju, nakon čega se upravljanje ponovo predaje korisniku.

# 6. 3D MODEL I FINALNI IZGLED PROJEKTA


Slika 4. - 3D model robota izrađen u FreeCAD-u


Slika 5. - Finalni izgled projektnog zadatka


Slika 6. - Maketa znaka STOP


Slika 7. - Model semafora

# 7. MOBILINA ANDROID APLIKACIJA

Kontrolni interfejs projekta realizovan je u obliku mobilne aplikacije za Android platformu. Aplikacija je razvijena u razvojnom okruženju Android Studio koristeći programski jezik Kotlin i moderan deklarativni okvir Jetpack Compose.

Glavne funkcionalnosti aplikacije obuhvataju:

- Upravljanje u realnom vremenu: Intuitivni korisnički interfejs sa komandama za navigaciju (naprijed, nazad, lijevo, desno) i kontrolu sigurnosnih funkcija (zvučni signal).
- Mrežna komunikacija: Slanje upravljačkih instrukcija putem HTTP protokola ka serveru na Raspberry Pi platformi unutar lokalne WiFi mreže.

Na sljedećim slikama prikazan je izgled ekrana mobilne aplikacije kada je aplikacija spremna za upotrebu, tačnije kada je aplikacija povezana sa serverom, kada aplikacija nije spojena sa serverom i prozor za postavku IP adrese i porta kako bi se aplikacija spojila na odgovarajući server.


Slika 8. - Glavni upravljački ekran


Slika 9. - Prikaz greške u konekciji


Slika 10. - Postavke mrežnih parametara

# 8. KOD

## 8.1. VERILOG KOD ZA KONTROLU DC MOTORA NA FPGA

module motor_driver (

input wire clk,

// movement controls from backend

input wire fwd_in,

input wire bwd_in,

input wire left_in,

input wire right_in,

input wire stoplight_in,

input wire stopsign_in,

input wire failsafe_in,

// line detectors

input wire ld_left,

input wire ld_right,

// motors (A0 A1 B0 B1)

output reg [3:0] m1_out, // left

output reg [3:0] m2_out, // right

output reg [2:0] state

);

// states

localparam STOP = 0, FORWARD = 1, BACKWARD = 2, LEFT = 3, RIGHT = 4;

always @(posedge clk) begin

// prioritize stop

if (failsafe_in == 1 || stoplight_in == 1 || stopsign_in == 1) begin

state = STOP;

end else if (fwd_in == 1) begin

// when moving forward check for lines

if (ld_left == 1) begin

state = RIGHT;

end else if (ld_right == 1) begin

state = LEFT;

end else begin

state = FORWARD;

end

end else if (bwd_in == 1) begin

state = BACKWARD;

end else if (right_in == 1) begin

state = RIGHT;

end else if (left_in == 1) begin

state = LEFT;

end else begin

state = STOP;

end

end

always @(state) begin

case (state)

FORWARD: begin

m1_out = 4'b0110;

m2_out = 4'b1001;

end

BACKWARD: begin

m1_out = 4'b1001;

m2_out = 4'b0110;

end

LEFT: begin

m1_out = 4'b0000;

m2_out = 4'b1001;

end

RIGHT: begin

m1_out = 4'b0110;

m2_out = 4'b0000;

end

STOP: begin

m1_out = 4'b0000;

m2_out = 4'b0000;

end

default: begin

m1_out = 4'b0000;

m2_out = 4'b0000;

end

endcase

end

endmodule

## 8.2. VERILOG KODA ZA IMPLEMENTACIJU KONTROLE ZVUČNE SIGNALIZACIJE PARKING SENZORA NA FPGA

module parking_sensor (

input wire clk,

input wire echo,

output reg trig,

output reg signal

);

localparam CLK_FREQ = 50000000;

localparam CYCLES_PER_CM = 2915;

localparam DIST_CONST = 10 * CYCLES_PER_CM;

localparam DIST_FAST = 15 * CYCLES_PER_CM;

localparam DIST_SLOW = 20 * CYCLES_PER_CM;

localparam TIME_500MS = CLK_FREQ / 2;

localparam TIME_250MS = CLK_FREQ / 4;

reg [21:0] trig_timer = 0;

reg [21:0] echo_width = 0;

reg [21:0] last_dist = 0;

reg [25:0] toggle_timer = 0;

always @(posedge clk) begin

// TRIGGER

if (trig_timer < 4000000) trig_timer <= trig_timer + 1;

else trig_timer <= 0;

trig <= (trig_timer > 0 && trig_timer < 500);

// ECHO

if (echo == 1) echo_width <= echo_width + 1;

else if (echo == 0 && echo_width > 0) begin

last_dist <= echo_width;

echo_width <= 0;

end

// TOGGLE TIMER

if (toggle_timer < CLK_FREQ) toggle_timer <= toggle_timer + 1;

else toggle_timer <= 0;

// PROXIMITY LOGIC

if (last_dist > DIST_SLOW || last_dist == 0) begin

signal <= 0;

end else if (last_dist > DIST_FAST) begin

signal <= (toggle_timer < TIME_500MS) ? 1 : 0;

end else if (last_dist > DIST_CONST) begin

signal <= (toggle_timer % (TIME_250MS * 2) < TIME_250MS) ? 1 : 0;

end else begin

signal <= 1;

end

end

endmodule

## 8.3. VERILOG KOD ZA INTEGRCIU SENZORA I MOTORA

module main (

input wire clk,

// movement controls

input wire fwd_in,

input wire bwd_in,

input wire left_in,

input wire right_in,

input wire stoplight_in,

input wire stopsign_in,

input wire failsafe_in,

// motors

output wire [3:0] m1_out,

output wire [3:0] m2_out,

output wire [2:0] md_state,

// parking sensors

input wire echo_fwd,

output wire trig_fwd,

input wire echo_bwd1,

output wire trig_bwd1,

input wire echo_bwd2,

output wire trig_bwd2,

// buzzer

input wire buzzer_in,

output wire buzzer,

// line detectors

input wire ld_left,

input wire ld_right

);

motor_driver md (

.clk(clk),

.fwd_in(fwd_in),

.bwd_in(bwd_in),

.left_in(left_in),

.right_in(right_in),

.stoplight_in(stoplight_in),

.stopsign_in(stopsign_in),

.failsafe_in(failsafe_in),

.ld_left(ld_left),

.ld_right(ld_right),

.m1_out(m1_out),

.m2_out(m2_out),

.state(md_state)

);

wire ps_buzzer_fwd, ps_buzzer_bwd1, ps_buzzer_bwd2;

assign buzzer = ps_buzzer_fwd | ps_buzzer_bwd1 | ps_buzzer_bwd2 | buzzer_in;

parking_sensor ps_fwd (

.clk(clk),

.echo(echo_fwd),

.trig(trig_fwd),

.signal(ps_buzzer_fwd)

);

parking_sensor ps_bwd1 (

.clk(clk),

.echo(echo_bwd1),

.trig(trig_bwd1),

.signal(ps_buzzer_bwd1)

);

parking_sensor ps_bwd2 (

.clk(clk),

.echo(echo_bwd2),

.trig(trig_bwd2),

.signal(ps_buzzer_bwd2)

);

endmodule

## 8.4. KOD NA RASPBERRY PI ZA DETEKCIJU SAOBRAĆAJNIH ZNAKOVA KORIŠTENJEM KAMERE

"""

detector.py

Detektor STOP znaka i crvenog svjetla na semaforu.

"""

import cv2

import numpy as np

import time

import threading

import collections

import argparse

import sys

import requests # <--- dodano za pitati Flask server da li se auto kreće

try:

import RPi.GPIO as GPIO

GPIO.setmode(GPIO.BCM)

HAVE_GPIO = True

except Exception:

HAVE_GPIO = False

# ---------- CONFIG ----------

CASCADE_PATH = "stop_sign.xml" # putanja do Haar Cascade modela za prepoznavanje STOP znaka

CAM_INDEX = 0

WORK_WIDTH = 640

WORK_HEIGHT = 480

STOP_HOLD_ACTIVE = False

STOP_HOLD_END = 0

USE_ROI = False # za detekciju samo unutar odredjene regije

ROI = (200, 50, 440, 380) # ima smisla samo ako je gornje True

# STOP znak

STOP_MIN_AREA = 1500 # minimalan povrsina u pixelima koju znak mora imat da bi bio detektovan

STOP_FRAMES_NEEDED = 3 # minimaln broj uzastopnih frame-ova da bi znak bio prepoznat

STOP_HOLD_SECONDS = 3.0 # koliko dugo zaustavljamo robot-a

STOP_COOLDOWN_SECONDS = 8.0 # koliko dugo imamo za pokrenut se

# konfiguracija detekcije crvenog svjetla

LOWER_RED1 = np.array([0, 120, 120])

UPPER_RED1 = np.array([10, 255, 255])

LOWER_RED2 = np.array([160, 120, 120])

UPPER_RED2 = np.array([179, 255, 255])

RED_MIN_AREA = 5

RED_MAX_AREA = 5000

RED_MIN_BRIGHTNESS = 30

LED_MAX_SIZE = 80

CIRCULARITY_MIN = 0.3

RED_FRAMES_ON_NEEDED = 10

RED_FRAMES_OFF_NEEDED = 10

GPIO_RED_PIN = 12 # pin na koji saljemo signal crvenog svjetla

GPIO_STOP_PIN = 16 # pin na koji saljemo signal nakon detekcije stop znaka

CASCADE_SCALE_FACTOR = 1.1

CASCADE_MIN_NEIGHBORS = 5

CASCADE_MIN_SIZE = (40, 40)

MORPH_KERNEL = np.ones((3, 3), np.uint8)

# ---------- CONFIG ----------

if HAVE_GPIO:

try:

GPIO.setup(GPIO_RED_PIN, GPIO.OUT, initial=GPIO.LOW)

GPIO.setup(GPIO_STOP_PIN, GPIO.OUT, initial=GPIO.LOW)

except Exception:

HAVE_GPIO = False

def gpio_write(pin, value):

if HAVE_GPIO:

try:

GPIO.output(pin, GPIO.HIGH if value else GPIO.LOW)

except Exception:

pass

class VideoCaptureThread:

def __init__(self, src, width, height):

self.cap = cv2.VideoCapture(src)

self.cap.set(cv2.CAP_PROP_FRAME_WIDTH, width)

self.cap.set(cv2.CAP_PROP_FRAME_HEIGHT, height)

self.frame = None

self.lock = threading.Lock()

self.stop_flag = False

threading.Thread(target=self._loop, daemon=True).start()

def _loop(self):

while not self.stop_flag:

ret, f = self.cap.read()

if ret:

with self.lock:

self.frame = f

def read(self):

with self.lock:

if self.frame is None:

return None

return self.frame.copy()

def stop(self):

self.stop_flag = True

try:

self.cap.release()

except:

pass

def apply_roi(img):

if not USE_ROI:

return img, (0, 0, img.shape[1], img.shape[0])

x1, y1, x2, y2 = ROI

roi_img = img[y1:y2, x1:x2]

return roi_img, (x1, y1, x2, y2)

# ucitavanje Cascade modela za detekciju stop znaka

cascade = cv2.CascadeClassifier(CASCADE_PATH)

if cascade.empty():

print("ERROR loading cascade")

sys.exit(1)

# historija prepoznatih objekata

stop_history = collections.deque(maxlen=STOP_FRAMES_NEEDED)

red_on_history = collections.deque(maxlen=RED_FRAMES_ON_NEEDED)

red_off_history = collections.deque(maxlen=RED_FRAMES_OFF_NEEDED)

stop_cooldown_end = 0

last_stop_time = 0

red_state = False

stop_detected_once = False # flag da STOP znak ne detektuje više puta dok auto ne krene

FLASK_URL = "http://192.168.1.132:5000" # <--- postavit na static ip kad bude bio

def main():

global last_stop_time, red_state, stop_detected_once, stop_cooldown_end

parser = argparse.ArgumentParser()

parser.add_argument("--no-gui", action="store_true")

parser.add_argument("--camera", type=int, default=CAM_INDEX)

args = parser.parse_args()

cap = VideoCaptureThread(args.camera, WORK_WIDTH, WORK_HEIGHT)

print("Running...")

try:

while True:

frame = cap.read()

if frame is None:

time.sleep(0.01)

continue

frame = cv2.resize(frame, (WORK_WIDTH, WORK_HEIGHT))

roi_frame, (rx1, ry1, rx2, ry2) = apply_roi(frame)

# detekcija stop znaka

gray = cv2.cvtColor(roi_frame, cv2.COLOR_BGR2GRAY)

stops = cascade.detectMultiScale(

gray,

scaleFactor=CASCADE_SCALE_FACTOR,

minNeighbors=CASCADE_MIN_NEIGHBORS,

minSize=CASCADE_MIN_SIZE

)

best_stop = None

best_area = 0

for (x, y, w, h) in stops:

area = w * h

ar = w / float(h)

if area >= STOP_MIN_AREA and 0.6 <= ar <= 1.6:

if area > best_area:

best_area = area

best_stop = (x, y, w, h)

stop_history.append(1 if best_stop else 0)

stop_confirmed = len(stop_history) == STOP_FRAMES_NEEDED and all(stop_history)

# kad se auto pocne kretat poslije stop znaka, resetuj flag

try:

r = requests.get(f"{FLASK_URL}/is_moving", timeout=0.1)

moving = r.json().get("moving", False)

except:

moving = False

if moving:

stop_detected_once = False

# detekcija stop znaka

# 1. Modify the STOP detection condition

# Added check: time.time() > stop_cooldown_end

global STOP_HOLD_ACTIVE, STOP_HOLD_END

if stop_confirmed and not stop_detected_once and time.time() > stop_cooldown_end:

last_stop_time = time.time()

print("[EVENT] STOP SIGN detected")

gpio_write(GPIO_STOP_PIN, True)

STOP_HOLD_ACTIVE = True

STOP_HOLD_END = time.time() + STOP_HOLD_SECONDS

stop_detected_once = True

# 2. Modify the STOP HOLD release logic

if STOP_HOLD_ACTIVE and time.time() >= STOP_HOLD_END:

gpio_write(GPIO_STOP_PIN, False)

STOP_HOLD_ACTIVE = False

# Set the cooldown to start NOW for 5 seconds

stop_cooldown_end = time.time() + STOP_COOLDOWN_SECONDS

print(f"[EVENT] STOP HOLD ended. Cooldown active for {STOP_COOLDOWN_SECONDS}s")

# 3. Optional: Clean up the moving reset

# You might want to keep stop_detected_once = True until the cooldown ends

# to be doubly sure it doesn't flicker.

try:

r = requests.get(f"{FLASK_URL}/is_moving", timeout=0.1)

moving = r.json().get("moving", False)

except:

moving = False

# Only reset the flag if the car is moving AND the cooldown has passed

if moving and time.time() > stop_cooldown_end:

stop_detected_once = False

# detekcija crvenog svjetla

hsv = cv2.cvtColor(roi_frame, cv2.COLOR_BGR2HSV)

m1 = cv2.inRange(hsv, LOWER_RED1, UPPER_RED1)

m2 = cv2.inRange(hsv, LOWER_RED2, UPPER_RED2)

mask = cv2.bitwise_or(m1, m2)

mask = cv2.morphologyEx(mask, cv2.MORPH_OPEN, MORPH_KERNEL)

mask = cv2.morphologyEx(mask, cv2.MORPH_CLOSE, MORPH_KERNEL)

contours, _ = cv2.findContours(mask, cv2.RETR_EXTERNAL, cv2.CHAIN_APPROX_SIMPLE)

detected_red = False

red_bbox = None

if contours:

c = max(contours, key=cv2.contourArea)

area = cv2.contourArea(c)

if RED_MIN_AREA <= area <= RED_MAX_AREA:

x, y, w, h = cv2.boundingRect(c)

if w <= LED_MAX_SIZE and h <= LED_MAX_SIZE:

v = hsv[y:y+h, x:x+w, 2]

mean_v = int(np.mean(v)) if v.size else 0

if mean_v >= RED_MIN_BRIGHTNESS:

per = cv2.arcLength(c, True)

if per > 0:

circularity = 4 * np.pi * area / (per * per)

else:

circularity = 0

if circularity >= CIRCULARITY_MIN:

detected_red = True

red_bbox = (x, y, w, h)

red_on_history.append(1 if detected_red else 0)

if detected_red:

red_off_history.clear()

else:

red_off_history.append(1)

if not red_state:

if len(red_on_history) == RED_FRAMES_ON_NEEDED and all(red_on_history):

red_state = True

print("[EVENT] RED LED ON")

#gpio_write(GPIO_RED_PIN, True)

else:

if len(red_off_history) == RED_FRAMES_OFF_NEEDED and all(red_off_history):

red_state = False

print("[EVENT] RED LED OFF")

#gpio_write(GPIO_RED_PIN, False)

display = frame.copy()

if USE_ROI:

cv2.rectangle(display, (rx1, ry1), (rx2, ry2), (255, 255, 0), 1)

if best_stop:

x, y, w, h = best_stop

x += rx1; y += ry1

cv2.rectangle(display, (x, y), (x+w, y+h), (0, 255, 0), 2)

cv2.putText(display, "STOP", (x, y-6), cv2.FONT_HERSHEY_SIMPLEX, 0.7, (0, 255, 0), 2)

if red_bbox:

x, y, w, h = red_bbox

x += rx1; y += ry1

cv2.rectangle(display, (x, y), (x+w, y+h), (0, 0, 255), 2)

cv2.putText(display, "RED", (x, y-6), cv2.FONT_HERSHEY_SIMPLEX, 0.7, (0, 0, 255), 2)

status = "RED: ON" if red_state else "RED: OFF"

cv2.putText(display, status, (10, display.shape[0]-10),

cv2.FONT_HERSHEY_SIMPLEX, 0.8,

(0, 0, 255) if red_state else (0, 255, 0), 2)

if not args.no_gui:

cv2.imshow("Detection", display)

cv2.imshow("Mask", mask)

if cv2.waitKey(1) & 0xFF == ord('q'):

break

time.sleep(0.001)

except KeyboardInterrupt:

print("Stopping...")

finally:

cap.stop()

if not args.no_gui:

cv2.destroyAllWindows()

if HAVE_GPIO:

GPIO.cleanup()

if __name__ == "__main__":

main()

stop_sign.xml je moguće pogledati klikom na link [13] koji se nalazi unutar naslova reference.

## 8.5. KOD ZA KOMUNIKACIU IZMEĐU MOBILNE APLIKACIJE I RASPBERRY PI

from flask import Flask, jsonify, request

from picamera2 import Picamera2

import RPi.GPIO as GPIO

import time

import threading

app = Flask(__name__)

# PINOUT

PIN_FWD = 4

PIN_BWD = 27

PIN_STOP = 22

PIN_LEFT = 23

PIN_RIGHT = 24

FAILSAFE = 26

PIN_HORN = 17

PINS = [PIN_FWD, PIN_BWD, PIN_STOP, PIN_LEFT, PIN_RIGHT]

GPIO.setmode(GPIO.BCM)

GPIO.setup(PINS, GPIO.OUT, initial=GPIO.LOW)

GPIO.setup(FAILSAFE, GPIO.OUT, initial=GPIO.LOW)

GPIO.setup(PIN_HORN, GPIO.OUT, initial = GPIO.HIGH)

motor_state = {"fwd": False, "bwd": False, "left": False, "right": False, "stop": False}

state_lock = threading.Lock()

last_move_time = time.time()

last_heartbeat_time = time.time() # vrijeme posljednjeg heartbeat-a

HEARTBEAT_TIMEOUT = 0.3 # 300 ms

last_seq = -1

def handle_header():

global last_seq

seq = int(request.headers.get("sequence"))

if(seq > last_seq):

last_seq = seq

print(seq)

return True

return False

picam = Picamera2()

picam.configure(picam.create_video_configuration())

picam.start()

def gen():

while True:

frame = picam.capture_array()

_, jpeg = cv2.imencode('.jpg', frame)

yield (b'--frame\r\n'

b'Content-Type: image/jpeg\r\n\r\n' +

jpeg.tobytes() + b'\r\n')

def set_motor(cmd, value=True):

with state_lock:

motor_state[cmd] = value

# ---------- Fail-safe heartbeat checker ----------

def heartbeat_loop():

global last_heartbeat_time

while True:

now = time.time()

if now - last_heartbeat_time > HEARTBEAT_TIMEOUT:

# ako je > timeout, posalji na failsafe pin signal, zaustavi sve

with state_lock:

for key in motor_state:

motor_state[key] = False

GPIO.output(FAILSAFE, GPIO.LOW)

time.sleep(0.01)

threading.Thread(target=heartbeat_loop, daemon=True).start()

@app.route("/heartbeat", methods=["POST"])

def heartbeat():

global last_heartbeat_time

last_heartbeat_time = time.time()

return jsonify({"status": "ok"})

@app.route("/forward/on")

def forward_on():

global last_move_time

last_move_time = time.time()

if(handle_header()):

GPIO.output(PIN_FWD, GPIO.HIGH)

return jsonify({"status": "forward ON"})

@app.route("/is_moving")

def is_moving():

moving = (time.time() - last_move_time) < 0.5

return jsonify({"moving": moving})

@app.route("/forward/off")

def forward_off():

if(handle_header()):

GPIO.output(PIN_FWD, GPIO.LOW)

return jsonify({"status": "forward OFF"})

@app.route("/backward/on")

def backward_on():

if(handle_header()):

GPIO.output(PIN_BWD, GPIO.HIGH)

return jsonify({"status": "backward ON"})

@app.route("/backward/off")

def backward_off():

if(handle_header()):

GPIO.output(PIN_BWD, GPIO.LOW)

return jsonify({"status": "backward OFF"})

@app.route("/left/on")

def left_on():

global last_move_time

last_move_time = time.time()

if(handle_header()):

GPIO.output(PIN_LEFT, GPIO.HIGH)

return jsonify({"status": "left ON"})

@app.route("/left/off")

def left_off():

if(handle_header()):

GPIO.output(PIN_LEFT, GPIO.LOW)

return jsonify({"status": "left OFF"})

@app.route("/right/on")

def right_on():

global last_move_time

last_move_time = time.time()

if(handle_header()):

GPIO.output(PIN_RIGHT, GPIO.HIGH)

return jsonify({"status": "right ON"})

@app.route("/right/off")

def right_off():

if(handle_header()):

GPIO.output(PIN_RIGHT, GPIO.LOW)

return jsonify({"status": "right OFF"})

@app.route("/horn/on")

def horn_on():

if(handle_header()):

GPIO.output(PIN_HORN, GPIO.HIGH)

return jsonify({"status": "horn ON"})

@app.route("/horn/off")

def horn_off():

if(handle_header()):

GPIO.output(PIN_HORN, GPIO.LOW)

return jsonify({"status" : "horn OFF"})

@app.route("/stop")

def stop_all():

GPIO.output(PIN_FWD, GPIO.LOW)

GPIO.output(PIN_BWD, GPIO.LOW)

GPIO.output(PIN_LEFT, GPIO.LOW)

GPIO.output(PIN_RIGHT, GPIO.LOW)

return jsonify({"status": "all stopped"})

@app.route("/")

def index():

return "Backend running"

if __name__ == "__main__":

app.run(host="0.0.0.0", port=5000)

## 8.6. KOD ZA SIMULACIJU RADA SEMAFORA

const static byte Rp = 1;

const static byte Yp = 0;

const static byte Gp = 2;

const static int BASE_DELAY = 2000;

const static int RED_DELAY = 3 * BASE_DELAY;

const static int RED_YELLOW_DELAY = 2 * BASE_DELAY;

const static int GREEN_DELAY = 2 * BASE_DELAY;

const static int GREEN_YELLOW_DELAY = 1 * BASE_DELAY;

void setup() {

pinMode(Rp, OUTPUT);

pinMode(Yp, OUTPUT);

pinMode(Gp, OUTPUT);

}

void loop() {

digitalWrite(Rp, HIGH);

digitalWrite(Yp, LOW);

digitalWrite(Gp, LOW);

delay(RED_DELAY);

digitalWrite(Rp, LOW);

digitalWrite(Yp, HIGH);

digitalWrite(Gp, LOW);

delay(RED_YELLOW_DELAY);

digitalWrite(Rp, LOW);

digitalWrite(Yp, LOW);

digitalWrite(Gp, HIGH);

delay(GREEN_DELAY);

digitalWrite(Rp, LOW);

digitalWrite(Yp, HIGH);

digitalWrite(Gp, LOW);

delay(GREEN_YELLOW_DELAY);}

## 8.7. KOTLIN KOD ZA ANDROID MOBILNU APLIKACIJU

Kod mobilne aplikacije je raspoređen u sljedećim fajlovima.

### 8.7.1. data/models/RobotStatus.kt

package com.example.robotcontrolapp.data.models

data class RobotStatus(

val connected: Boolean = false,

val moving: Boolean = false,

val lastCommand: String = "none"

)

data class ControlResponse(

val status: String

)

enum class Direction(val value: String) {

FORWARD("forward"),

BACKWARD("backward"),

LEFT("left"),

RIGHT("right"),

STOP("stop")

}

### 8.7.2. data/RobotRepository.kt

package com.example.robotcontrolapp.data

import com.example.robotcontrolapp.data.models.ControlResponse

import com.example.robotcontrolapp.data.models.RobotStatus

import com.example.robotcontrolapp.network.RetrofitClient

import kotlinx.coroutines.Dispatchers

import kotlinx.coroutines.delay

import kotlinx.coroutines.flow.Flow

import kotlinx.coroutines.flow.flow

import kotlinx.coroutines.flow.flowOn

import kotlinx.coroutines.withContext

import retrofit2.Response

class RobotRepository {

private val apiService = RetrofitClient.apiService

fun startHeartbeat(): Flow<Result<Unit>> = flow {

while (true) {

try {

val response = apiService.sendHeartbeat()

if (response.isSuccessful) {

emit(Result.success(Unit))

} else {

emit(Result.failure(Exception("Heartbeat failed")))

}

} catch (e: Exception) {

emit(Result.failure(e))

}

delay(1000)

}

}.flowOn(Dispatchers.IO)

suspend fun forwardOn(seq: Int): Result<ControlResponse> {

return executeRequest { apiService.forwardOn(seq) }}

suspend fun forwardOff(seq: Int): Result<ControlResponse> {

return executeRequest { apiService.forwardOff(seq) }}

suspend fun backwardOn(seq: Int): Result<ControlResponse> {

return executeRequest { apiService.backwardOn(seq) }}

suspend fun backwardOff(seq: Int): Result<ControlResponse> {

return executeRequest { apiService.backwardOff(seq) }}

suspend fun leftOn(seq: Int): Result<ControlResponse> {

return executeRequest { apiService.leftOn(seq) }}

suspend fun leftOff(seq: Int): Result<ControlResponse> {

return executeRequest { apiService.leftOff(seq) }}

suspend fun rightOn(seq: Int): Result<ControlResponse> {

return executeRequest { apiService.rightOn(seq) }}

suspend fun rightOff(seq: Int): Result<ControlResponse> {

return executeRequest { apiService.rightOff(seq) }}

suspend fun stopAll(seq: Int): Result<ControlResponse> {

return executeRequest { apiService.stopAll(seq) }}

suspend fun hornOn(seq: Int): Result<ControlResponse> {

return executeRequest { apiService.hornOn(seq) }

}

suspend fun hornOff(seq: Int): Result<ControlResponse> {

return executeRequest { apiService.hornOff(seq) }

}

fun getRobotStatusFlow(): Flow<Result<RobotStatus>> = flow {

while (true) {

try {

val response = apiService.isMoving()

if (response.isSuccessful && response.body() != null) {

emit(Result.success(response.body()!!))

} else {

emit(Result.failure(Exception("Failed to get status")))

}

} catch (e: Exception) {

emit(Result.failure(e))

}

delay(500)

}

}.flowOn(Dispatchers.IO)

private suspend fun executeRequest(

request: suspend () -> Response<ControlResponse>

): Result<ControlResponse> {

return withContext(Dispatchers.IO) {

try {

val response = request()

if (response.isSuccessful && response.body() != null) {

Result.success(response.body()!!)

} else {

Result.failure(Exception("Request failed: ${response.code()}"))

}

} catch (e: Exception) {

Result.failure(e)

}

}

}

fun updateRobotIp(ip: String, port: Int = 5000) {

RetrofitClient.updateBaseUrl(ip, port)

}

}

### 8.7.3. network/RetrofitClient.kt

package com.example.robotcontrolapp.network

import okhttp3.OkHttpClient

import okhttp3.logging.HttpLoggingInterceptor

import retrofit2.Retrofit

import retrofit2.converter.gson.GsonConverterFactory

import java.util.concurrent.TimeUnit

object RetrofitClient {

private const val DEFAULT_IP = "192.168.1.132"

private const val DEFAULT_PORT = 5000

private var currentBaseUrl = "http://$DEFAULT_IP:$DEFAULT_PORT/"

private val loggingInterceptor = HttpLoggingInterceptor().apply {

level = HttpLoggingInterceptor.Level.BODY

}

private val okHttpClient = OkHttpClient.Builder()

.addInterceptor(loggingInterceptor)

.connectTimeout(5, TimeUnit.SECONDS)

.readTimeout(5, TimeUnit.SECONDS)

.writeTimeout(5, TimeUnit.SECONDS)

.build()

private fun createRetrofit(baseUrl: String): Retrofit {

return Retrofit.Builder()

.baseUrl(baseUrl)

.client(okHttpClient)

.addConverterFactory(GsonConverterFactory.create())

.build()

}

private var retrofit = createRetrofit(currentBaseUrl)

val apiService: RobotApiService

get() = retrofit.create(RobotApiService::class.java)

fun updateBaseUrl(ip: String, port: Int = DEFAULT_PORT) {

currentBaseUrl = "http://$ip:$port/"

retrofit = createRetrofit(currentBaseUrl)

}

}

### 8.7.4. network/RobotApiService.kt

package com.example.robotcontrolapp.network

import com.example.robotcontrolapp.data.models.ControlResponse

import com.example.robotcontrolapp.data.models.RobotStatus

import retrofit2.Response

import retrofit2.http.GET

import retrofit2.http.Header

import retrofit2.http.POST

interface RobotApiService {

@POST("heartbeat")

suspend fun sendHeartbeat(@Header("sequence") seq : Int): Response<ControlResponse>

@GET("forward/on")

suspend fun forwardOn(@Header("sequence") seq : Int): Response<ControlResponse>

@GET("forward/off")

suspend fun forwardOff(@Header("sequence") seq : Int): Response<ControlResponse>

@GET("backward/on")

suspend fun backwardOn(@Header("sequence") seq : Int): Response<ControlResponse>

@GET("backward/off")

suspend fun backwardOff(@Header("sequence") seq : Int): Response<ControlResponse>

@GET("left/on")

suspend fun leftOn(@Header("sequence") seq : Int): Response<ControlResponse>

@GET("left/off")

suspend fun leftOff(@Header("sequence") seq : Int): Response<ControlResponse>

@GET("right/on")

suspend fun rightOn(@Header("sequence") seq : Int): Response<ControlResponse>

@GET("right/off")

suspend fun rightOff(@Header("sequence") seq : Int): Response<ControlResponse>

@GET("stop")

suspend fun stopAll(): Response<ControlResponse>

@GET("horn/on")

suspend fun hornOn(@Header("sequence") seq : Int): Response<ControlResponse>

@GET("horn/off")

suspend fun hornOff(@Header("sequence") seq : Int): Response<ControlResponse>

@GET("is_moving")

suspend fun isMoving(): Response<RobotStatus>

}

### 8.7.5. ui/components/ActionButton.kt

package com.example.robotcontrolapp.ui.components

import androidx.compose.foundation.Image

import androidx.compose.foundation.background

import androidx.compose.foundation.gestures.detectTapGestures

import androidx.compose.foundation.layout.*

import androidx.compose.foundation.shape.RoundedCornerShape

import androidx.compose.material3.MaterialTheme

import androidx.compose.runtime.Composable

import androidx.compose.ui.Alignment

import androidx.compose.ui.Modifier

import androidx.compose.ui.draw.clip

import androidx.compose.ui.graphics.Color

import androidx.compose.ui.input.pointer.pointerInput

import androidx.compose.ui.layout.ContentScale

import androidx.compose.ui.res.painterResource

import androidx.compose.ui.res.stringResource

import androidx.compose.ui.unit.dp

@Composable

fun ActionButton(

imageId: Int,

labelId: Int,

isActive: Boolean,

color: Color,

onPress: () -> Unit,

onRelease: () -> Unit,

modifier: Modifier = Modifier

) {

Box(

modifier = modifier

.size(80.dp)

.clip(RoundedCornerShape(12.dp))

.background(color)

.pointerInput(Unit) {

detectTapGestures(

onPress = {

onPress()

tryAwaitRelease()

onRelease()}

)},

contentAlignment = Alignment.Center

) {

Image(

painter = painterResource(imageId),

contentDescription = stringResource(labelId),

modifier = Modifier.size(40.dp),

contentScale = ContentScale.FillBounds)

}}

### 8.7.6. ui/components/ControlPad.kt

package com.example.robotcontrolapp.ui.components

import androidx.compose.foundation.background

import androidx.compose.foundation.gestures.detectTapGestures

import androidx.compose.foundation.layout.*

import androidx.compose.foundation.shape.RoundedCornerShape

import androidx.compose.material.icons.Icons

import androidx.compose.material.icons.automirrored.filled.KeyboardArrowRight

import androidx.compose.material.icons.filled.KeyboardArrowDown

import androidx.compose.material.icons.filled.KeyboardArrowLeft

import androidx.compose.material.icons.filled.KeyboardArrowRight

import androidx.compose.material.icons.filled.KeyboardArrowUp

import androidx.compose.material3.Icon

import androidx.compose.material3.MaterialTheme

import androidx.compose.runtime.*

import androidx.compose.ui.Alignment

import androidx.compose.ui.Modifier

import androidx.compose.ui.draw.clip

import androidx.compose.ui.graphics.vector.ImageVector

import androidx.compose.ui.input.pointer.pointerInput

import androidx.compose.ui.unit.dp

import com.example.robotcontrolapp.data.models.Direction

import com.example.robotcontrolapp.ui.theme.ControlButtonActive

import com.example.robotcontrolapp.ui.theme.ControlButtonInactive

@Composable

fun ControlButton(

icon: ImageVector,

direction: Direction,

isPressed: Boolean,

onPress: () -> Unit,

onRelease: () -> Unit,

modifier: Modifier = Modifier

) {

Box(

modifier = modifier

.size(80.dp)

.clip(RoundedCornerShape(12.dp))

.background(

if (isPressed) ControlButtonActive

else ControlButtonInactive

)

.pointerInput(Unit) {

detectTapGestures(

onPress = {

onPress()

tryAwaitRelease()

onRelease()

}

)

},

contentAlignment = Alignment.Center

) {

Icon(

imageVector = icon,

contentDescription = direction.value,

tint = MaterialTheme.colorScheme.onPrimary,

modifier = Modifier.size(40.dp)

)

}

}

@Composable

fun ControlPad(

currentDirection: Direction,

onDirectionChange: (Direction) -> Unit,

onStop: () -> Unit,

modifier: Modifier = Modifier

) {

Column(

modifier = modifier,

horizontalAlignment = Alignment.CenterHorizontally,

verticalArrangement = Arrangement.spacedBy(16.dp)

) {

ControlButton(

icon = Icons.Default.KeyboardArrowUp,

direction = Direction.FORWARD,

isPressed = currentDirection == Direction.FORWARD,

onPress = { onDirectionChange(Direction.FORWARD) },

onRelease = onStop

)

Row(

horizontalArrangement = Arrangement.spacedBy(16.dp),

verticalAlignment = Alignment.CenterVertically

) {

ControlButton(

icon = Icons.Default.KeyboardArrowLeft,

direction = Direction.LEFT,

isPressed = currentDirection == Direction.LEFT,

onPress = { onDirectionChange(Direction.LEFT) },

onRelease = onStop

)

ControlButton(

icon = Icons.Default.KeyboardArrowDown,

direction = Direction.BACKWARD,

isPressed = currentDirection == Direction.BACKWARD,

onPress = { onDirectionChange(Direction.BACKWARD) },

onRelease = onStop

)

ControlButton(

icon = Icons.AutoMirrored.Filled.KeyboardArrowRight,

direction = Direction.RIGHT,

isPressed = currentDirection == Direction.RIGHT,

onPress = { onDirectionChange(Direction.RIGHT) },

onRelease = onStop

)

}

}

}

### 8.7.7. ui/screens/MainActivity.kt

package com.example.robotcontrolapp.ui.screens

import android.os.Bundle

import androidx.activity.ComponentActivity

import androidx.activity.compose.setContent

import androidx.activity.enableEdgeToEdge

import androidx.compose.foundation.layout.fillMaxSize

import androidx.compose.material3.MaterialTheme

import androidx.compose.material3.Surface

import androidx.compose.ui.Modifier

import androidx.lifecycle.viewmodel.compose.viewModel

import com.example.robotcontrolapp.ui.theme.RobotControlAppTheme

import com.example.robotcontrolapp.viewmodel.RobotViewModel

class MainActivity : ComponentActivity() {

override fun onCreate(savedInstanceState: Bundle?) {

super.onCreate(savedInstanceState)

enableEdgeToEdge()

setContent {

RobotControlAppTheme {

Scaffold(modifier = Modifier.fillMaxSize()) { innerPadding ->

Surface(

modifier = Modifier

.fillMaxSize()

.padding(innerPadding),

color = MaterialTheme.colorScheme.background

) {

val viewModel: RobotViewModel = viewModel()

RobotControlScreen(viewModel = viewModel)

}

}

}

}

### 8.7.8. ui/screens/RobotControlScreen.kt

package com.example.robotcontrolapp.ui.screens

import androidx.compose.foundation.background

import androidx.compose.foundation.border

import androidx.compose.foundation.layout.*

import androidx.compose.foundation.shape.RoundedCornerShape

import androidx.compose.material.icons.Icons

import androidx.compose.material.icons.filled.Settings

import androidx.compose.material3.*

import androidx.compose.runtime.*

import androidx.compose.ui.Alignment

import androidx.compose.ui.Modifier

import androidx.compose.ui.graphics.Color

import androidx.compose.ui.text.font.FontWeight

import androidx.compose.ui.text.style.TextAlign

import androidx.compose.ui.unit.dp

import androidx.compose.ui.unit.sp

import androidx.compose.ui.window.Dialog

import androidx.lifecycle.compose.collectAsStateWithLifecycle

import com.example.robotcontrolapp.ui.components.ActionButton

import com.example.robotcontrolapp.ui.components.ControlPad

import com.example.robotcontrolapp.ui.theme.EmergencyRed

import com.example.robotcontrolapp.ui.theme.StatusWarning

import com.example.robotcontrolapp.viewmodel.RobotViewModel

import com.example.robotcontrolapp.R

import com.example.robotcontrolapp.ui.theme.EmergencyRedActive

import com.example.robotcontrolapp.ui.theme.StatusWarningActive

import com.example.robotcontrolapp.viewmodel.StopReason

@Composable

fun RobotControlScreen(

viewModel: RobotViewModel,

modifier: Modifier = Modifier

) {

val uiState by viewModel.uiState.collectAsStateWithLifecycle()

Box(

modifier = modifier

.fillMaxSize()

.background(MaterialTheme.colorScheme.background)

.padding(24.dp)

) {

IconButton(

onClick = { viewModel.toggleSettings() },

modifier = Modifier.align(Alignment.TopEnd)

) {

Icon(

imageVector = Icons.Default.Settings,

contentDescription = "Settings",

tint = MaterialTheme.colorScheme.onBackground,

modifier = Modifier.size(32.dp)

)

}

Row(

modifier = Modifier.align(Alignment.Center).fillMaxWidth(),

horizontalArrangement = Arrangement.SpaceBetween,

verticalAlignment = Alignment.CenterVertically

) {

Column(verticalArrangement = Arrangement.spacedBy(24.dp)) {

ActionButton(

imageId = R.drawable.horn,

labelId = R.string.horn,

color = if (uiState.isHornActive) StatusWarningActive else StatusWarning,

isActive = uiState.isHornActive,

onPress = { viewModel.activateHorn() },

onRelease = { viewModel.releaseHorn() }

)

}

ControlPad(

currentDirection = uiState.currentDirection,

onDirectionChange = { viewModel.sendCommand(it) },

onStop = { viewModel.stopCommand() }

)

}

Column(

modifier = Modifier

.align(Alignment.BottomCenter)

.padding(bottom = 20.dp)

.fillMaxWidth(),

horizontalAlignment = Alignment.CenterHorizontally,

verticalArrangement = Arrangement.spacedBy(10.dp)

) {

if (!uiState.isConnected && uiState.errorMessage != null) {

InfoWhiteBox(

message = uiState.errorMessage!!,

isError = true

)

}

if (uiState.stopReason != StopReason.NONE) {

val stopMessage = when (uiState.stopReason) {

StopReason.RED_LIGHT -> "Robot stopped: RED LIGHT DETECTED!"

StopReason.STOP_SIGN -> "Robot stopped: STOP SIGN DETECTED!"

else -> ""

}

if (stopMessage.isNotEmpty()) {

InfoWhiteBox(

message = stopMessage,

isError = false,

onDismiss = { viewModel.handleStopReason(StopReason.NONE) }

)

}

}

if (uiState.isConnected) {

Card(

colors = CardDefaults.cardColors(

containerColor = MaterialTheme.colorScheme.surfaceVariant

)

) {

Text(

text = "Robot Status: ${if (uiState.status.moving) "Moving" else "Stopped"}",

modifier = Modifier.padding(16.dp),

style = MaterialTheme.typography.bodyLarge

)

}

}

}

}

if (uiState.showSettings) {

SettingsDialog(

onDismiss = { viewModel.toggleSettings() },

onConnect = { ip, port ->

viewModel.connectToRobot(ip, port)

viewModel.toggleSettings()

}

)

}

}

@Composable

fun InfoWhiteBox(

message: String,

isError: Boolean,

onDismiss: (() -> Unit)? = null

) {

Card(

modifier = Modifier

.fillMaxWidth(0.95f)

.border(2.dp, if (isError) Color.Red else Color.Black, RoundedCornerShape(12.dp)),

shape = RoundedCornerShape(12.dp),

colors = CardDefaults.cardColors(containerColor = Color.White),

elevation = CardDefaults.cardElevation(8.dp)

) {

Row(

modifier = Modifier

.padding(horizontal = 16.dp, vertical = 12.dp)

.fillMaxWidth(),

verticalAlignment = Alignment.CenterVertically,

horizontalArrangement = Arrangement.SpaceBetween

){

Text(

text = message,

color = Color.Black,

fontSize = 14.sp,

fontWeight = FontWeight.Bold,

modifier = Modifier.weight(1f)

)

if (onDismiss != null) {

TextButton(onClick = onDismiss, contentPadding = PaddingValues(start = 8.dp)) {

Text("OK", color = Color.Blue, fontWeight = FontWeight.Black, fontSize = 15.sp)

}

}

}

}

}

@Composable

fun SettingsDialog(

onDismiss: () -> Unit,

onConnect: (String, Int) -> Unit

) {

var ipAddress by remember { mutableStateOf("192.168.1.100") }

var port by remember { mutableStateOf("5000") }

Dialog(onDismissRequest = onDismiss) {

Card(

modifier = Modifier.fillMaxWidth().padding(16.dp),

shape = RoundedCornerShape(16.dp)

) {

Column(

modifier = Modifier.padding(24.dp),

verticalArrangement = Arrangement.spacedBy(16.dp)

) {

Text(text = "Postavke Robota", style = MaterialTheme.typography.titleLarge)

OutlinedTextField(

value = ipAddress,

onValueChange = { ipAddress = it },

label = { Text("IP Adresa") },

modifier = Modifier.fillMaxWidth(),

singleLine = true

)

OutlinedTextField(

value = port,

onValueChange = { port = it },

label = { Text("Port") },

modifier = Modifier.fillMaxWidth(),

singleLine = true

)

Row(

modifier = Modifier.fillMaxWidth(),

horizontalArrangement = Arrangement.spacedBy(8.dp)

) {

TextButton(onClick = onDismiss, modifier = Modifier.weight(1f)) {

Text("Otkaži")

}

Button(

onClick = {

val portInt = port.toIntOrNull() ?: 5000

onConnect(ipAddress, portInt)

},

modifier = Modifier.weight(1f)

) {

Text("Poveži")

}

}

}

}

}

}

### 8.7.9. viewmodel/RobotViewModel.kt

package com.example.robotcontrolapp.viewmodel

import androidx.lifecycle.ViewModel

import androidx.lifecycle.viewModelScope

import com.example.robotcontrolapp.data.RobotRepository

import com.example.robotcontrolapp.data.models.Direction

import com.example.robotcontrolapp.data.models.RobotStatus

import kotlinx.coroutines.Job

import kotlinx.coroutines.flow.MutableStateFlow

import kotlinx.coroutines.flow.StateFlow

import kotlinx.coroutines.flow.asStateFlow

import kotlinx.coroutines.flow.catch

import kotlinx.coroutines.flow.updateAndGet

import kotlinx.coroutines.launch

enum class StopReason {

NONE, RED_LIGHT, STOP_SIGN

}

data class RobotUiState(

val isConnected: Boolean = false,

val status: RobotStatus = RobotStatus(),

val currentDirection: Direction = Direction.STOP,

val isHornActive: Boolean = false,

val errorMessage: String? = "App is not connected to the server. Please try changing the IP address or port in the settings.",

val isLoading: Boolean = false,

val showSettings: Boolean = false,

val stopReason: StopReason = StopReason.NONE,

val currentIp: String = "192.168.1.132",

val currentPort: Int = 5000

val sequence: Int = 0

)

class RobotViewModel : ViewModel() {

private val repository = RobotRepository()

private val _uiState = MutableStateFlow(RobotUiState())

val uiState: StateFlow<RobotUiState> = _uiState.asStateFlow()

private var statusJob: Job? = null

private var heartbeatJob: Job? = null

private fun setConnectionError() {

val state = _uiState.value

val message = "Failed connection with the server at IP: ${state.currentIp} and Port: ${state.currentPort}. Please try changing the IP address or port in the settings."

_uiState.value = _uiState.value.copy(

errorMessage = message,

isConnected = false,

isLoading = false

)

}

fun connectToRobot(ip: String, port: Int = 5000) {

viewModelScope.launch {

_uiState.value = _uiState.value.copy(isLoading = true, currentIp = ip, currentPort = port)

try {

repository.updateRobotIp(ip, port)

startHeartbeat()

startStatusUpdates()

_uiState.value = _uiState.value.copy(

isConnected = true,

isLoading = false,

errorMessage = null

)

} catch (e: Exception) {

setConnectionError()

}

}

}

fun sendCommand(direction: Direction) {

viewModelScope.launch {

val seq = _uiState.updateAndGet {

it.copy(

currentDirection = direction,

stopReason = StopReason.NONE,

sequence = it.sequence + 1

)

}.sequence

val result = when (direction) {

Direction.FORWARD -> repository.forwardOn(seq)

Direction.BACKWARD -> repository.backwardOn(seq)

Direction.LEFT -> repository.leftOn(seq)

Direction.RIGHT -> repository.rightOn(seq)

Direction.STOP -> repository.stopAll()

}

result.onSuccess {

_uiState.value = _uiState.value.copy(errorMessage = null, isConnected = true)

}.onFailure {

setConnectionError()

}

}

}

fun stopCommand() {

viewModelScope.launch {

val currentDir = _uiState.value.currentDirection

val seq = _uiState.updateAndGet {

it.copy(

currentDirection = Direction.STOP,

sequence = it.sequence + 1

)

}.sequence

val result = when (currentDir) {

Direction.FORWARD -> repository.forwardOff(seq)

Direction.BACKWARD -> repository.backwardOff(seq)

Direction.LEFT -> repository.leftOff(seq)

Direction.RIGHT -> repository.rightOff(seq)

Direction.STOP -> repository.stopAll()

}

result.onFailure { setConnectionError() }

}

}

fun activateHorn() {

viewModelScope.launch {

val seq = _uiState.updateAndGet {

it.copy(

isHornActive = true,

sequence = it.sequence + 1

)

}.sequence

repository.hornOn(seq).onSuccess {

_uiState.value = _uiState.value.copy(errorMessage = null, isConnected = true)

}.onFailure {

setConnectionError()

}

}

}

fun releaseHorn() {

viewModelScope.launch {

val seq = _uiState.updateAndGet {

it.copy(

isHornActive = false,

sequence = it.sequence + 1

)

}.sequence

repository.hornOff(seq).onFailure { setConnectionError() } }

}

private fun startHeartbeat() {

heartbeatJob?.cancel()

heartbeatJob = viewModelScope.launch {

repository.startHeartbeat()

.catch { setConnectionError() }

.collect { result ->

result.onFailure { setConnectionError() }

}

}

}

private fun startStatusUpdates() {

statusJob?.cancel()

statusJob = viewModelScope.launch {

repository.getRobotStatusFlow()

.catch { setConnectionError() }

.collect { result ->

result.onSuccess { status ->

_uiState.value = _uiState.value.copy(

status = status,

isConnected = true,

errorMessage = null

)

}.onFailure { setConnectionError() }

}

}

}

fun handleStopReason(reason: StopReason) {

_uiState.value = _uiState.value.copy(stopReason = reason)

}

fun toggleSettings() {

_uiState.value = _uiState.value.copy(showSettings = !_uiState.value.showSettings)

}

fun clearError() {

_uiState.value = _uiState.value.copy(errorMessage = null)

}

}

### 8.7.10. Ostala podešavanja za rad aplikacije

Kako bi aplikacija komunicirala sa Raspberry PI, u AndroidMainfesst.xml file dodane su sljedeće permisije:

<uses-permission android:name="android.permission.INTERNET"/>

<uses-permission android:name="android.permission.ACCESS_NETWORK_STATE"/>

<uses-permission android:name="android.permission.ACCESS_WIFI_STATE"/>

Zatim, u file-u build.gradle.kts su dependencies prošireni sa sljedećim kodom:

// ============================================

// CORE ANDROID

// ============================================

implementation("androidx.core:core-ktx:1.12.0")

implementation("androidx.lifecycle:lifecycle-runtime-ktx:2.7.0")

implementation("androidx.activity:activity-compose:1.8.2")

// ============================================

// JETPACK COMPOSE

// ============================================

implementation(platform("androidx.compose:compose-bom:2024.01.00"))

implementation("androidx.compose.ui:ui")

implementation("androidx.compose.ui:ui-graphics")

implementation("androidx.compose.ui:ui-tooling-preview")

implementation("androidx.compose.material3:material3")

implementation("androidx.compose.material:material-icons-extended")

// ============================================

// LIFECYCLE & VIEWMODEL

// ============================================

implementation("androidx.lifecycle:lifecycle-viewmodel-compose:2.7.0")

implementation("androidx.lifecycle:lifecycle-runtime-compose:2.7.0")

implementation("androidx.lifecycle:lifecycle-viewmodel-ktx:2.7.0")

// ============================================

// NAVIGATION (ako bude potrebno kasnije)

// ============================================

implementation("androidx.navigation:navigation-compose:2.7.6")

// ============================================

// NETWORKING - RETROFIT & OKHTTP

// ============================================

implementation("com.squareup.retrofit2:retrofit:2.9.0")

implementation("com.squareup.retrofit2:converter-gson:2.9.0")

implementation("com.squareup.okhttp3:okhttp:4.12.0")

implementation("com.squareup.okhttp3:logging-interceptor:4.12.0")

// Gson za JSON parsing

implementation("com.google.code.gson:gson:2.10.1")

// ============================================

// IMAGE LOADING - COIL

// ============================================

implementation("io.coil-kt:coil-compose:2.5.0")

implementation("io.coil-kt:coil-gif:2.5.0")

// ============================================

// COROUTINES

// ============================================

implementation("org.jetbrains.kotlinx:kotlinx-coroutines-android:1.7.3")

implementation("org.jetbrains.kotlinx:kotlinx-coroutines-core:1.7.3")

Vizuelni izgled aplikacije definisan je unutar paketa ui/theme, gdje datoteke Color.kt, Type.kt i Theme.kt služe za konfiguraciju palete boja, tipografije i opšte teme korisničkog interfejsa. Grafički resursi, poput ikona za kontrolne tipke (buttons), smješteni su u drawable folder i koriste se za vizuelnu reprezentaciju komandi za upravljanje robotom.

# REFERENCE

[1] Cyclone II Device Handbook, Volume 1 – Architecture Chapter

https://cdrdv2-public.intel.com/654843/cyc2_cii51002.pdf

[2] Cyclone II Device Family Data Sheet

https://home.etf.rs/~vm/os/vlsi/razno/izabrano%20iz%20Altera%20Cyclone%202%20datasheet.pdf

[3] https://www.raspberrypi.org/

[4] https://www.raspberrypi.com/documentation/

[5] https://www.espressif.com/en/products/socs/esp8266

[6] https://components101.com/sensors/ultrasonic-sensor-working-pinout-datasheet

[7] https://www.logitech.com/en-us/software

[8] https://components101.com/sensors/ir-sensor-module

[9] https://www.electronicsforu.com/technology-trends/learn-electronics/ir-led-infrared-sensor-basics

[10] https://learn.sparkfun.com/tutorials/light-emitting-diodes-leds/all

[11] https://www.st.com/en/motor-drivers/l298.html

[12] https://components101.com/misc/buzzer-pinout-working-datasheet

[13] https://github.com/mahirsuljic-fet/PSoC-Projekat/tree/main

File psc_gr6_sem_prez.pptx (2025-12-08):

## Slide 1

ULTIMATIVNA PLATFORMA ZA FIZIČKI AI I APLIKACIJE U ROBOTICI

JETSON THOR

by NVIDIA

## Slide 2

Agenda

01 Fizički AI?

02 Jetson platforma

03 Inovacije i arhitektura

04 Računarska moć

04 Thor vs Orin

05 Prednosti i nedostaci

06 Primjena

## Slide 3

Uvod


Ubrzani razvoj robotike i fizičkog AI

Robotski sistemi postaju sve inteligentniji, a Physical AI omogućava robotima da razumiju i reaguju na stvarno okruženje u realnom vremenu.

1


Potreba za ultra-snažnim Edge AI rješenjima

Zbog ogromne količine senzorskih podataka, robotima je potrebna lokalna obrada, cloud je prespor i nepouzdan za kritične funkcije.

2


Zahtjevi autonomnih sistema

NVIDIA Jetson Thor donosi računalnu snagu server klase direktno na uređaj, što omogućava napredne autonomne funkcije bez kašnjenja.

3


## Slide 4


Fizički AI?

ŠTA JE FIZIČKI AI?

- Fizički AI spaja percepciju, razumijevanje i akciju
- Potrebna obrada u realnom vremenu
- Minimalna latencija bez cloud zavisnosti

Physical AI kombinuje senzorsku percepciju, razumijevanje okruženja i izvođenje akcija u realnom vremenu. Ovakvi sistemi zahtijevaju minimalnu latenciju i visoko optimizovane hardverske platforme koje mogu simultano obrađivati kompleksne podatke.

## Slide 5


Jetson platforma

JETSON LINIJA - EMBEDDED AI COMPUTING PLATFORMA

- Standard za Edge AI
- Primjena u robotici, autonomnoj vožnji i analitici
- Softwerska podrška: CUDA, Isaac, TensorRT

NVIDIA Jetson predstavlja seriju ugrađenih računarskih modula visokih performansi (System-on-Module - SoM) namijenjenih razvoju i implementaciji sistema umjetne inteligencije na rubu mreže (Edge AI).

Jetson moduli nude kompaktna i snažna rješenja za robotiku, autonomna vozila i naprednu video analitiku. Povezani su s NVIDIA AI softverskim ekosistemom, što omogućava jednostavnu integraciju i razvoj složenih AI aplikacija.

Jetson linija modula uključuje AGX Thor, AGX Orin, Orin NX, Orin Nano, AGX Xavier, Xavier NX, TX2 i Nano seriju.

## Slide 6

Jetson Thor

NAJNAPREDNIJA EDGE AI PLATFORMA

- Najsnažniji Jetson modul
- Dizajniran za generativnu AI i naprednu robotiku
- Nasljednik Orina

Jetson Thor se nalazi na vrhu Jetson serije i predstavlja najmoćniju NVIDIA Edge AI platformu. Donosi generacijski skok u performansama u odnosu na Orin, posebno u domeni generativne umjetne inteligencije.

Jetson Thor je predstavljen kao "Ultimate Platform for Physical AI" zbog svojih specifičnih hardverskih poboljšanja. Njegovo mjesto u Jetson liniji je na samom vrhu, pružajući neophodnu računarsku snagu za obradu podataka iz više senzora, pokretanje velikih vizualno-jezičnih modela i brze autonomne odluke koje su ključne za funkcionisanje humanoidnih robota i vozila sa Level 4 autonomijom

SoM je gotova hardverska jedinica koja integriše SoC čip zajedno s neophodnom DRAM memorijom, skladištem i I/O interfejsima na jednu ploču. Proizvođač isporučuje Jetson Thor kao SoM radi pojednostavljenja implementacije i brže integracije u ciljane robotske sisteme.

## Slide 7


KLJUČNE INOVACIJE

Jetson Thor

Grace CPU, Blackwell GPU i Transformer Engine zajedno omogućavaju pokretanje najnovijih LLM, VLM i multimodalnih modela. Ovaj dizajn čini Thor pogodnim za složenu robotiku i sistemske operacije u realnom vremenu.

Grace CPU

Blackwell GPU

Arhitektura

Transformer
Engine

Tensor Cores

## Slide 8

PRIMJENA

Sistemi na čipu

Heterogena integracija

Umjesto oslanjanja samo na CPU ili GPU, Jetson Thor SoC integriše raznovrsan skup specijalizovanih procesorskih jezgri

Energetska efikasnost i performanse (PPW)

Dizajniran da pruži maksimalnu snagu po vatu, kritično za robote koji rade na baterije

Masivna ulazno-izlazna propusnost

Za Fizičku AI, potrebno je istovremeno obrađivati podatke s velikog broja senzora (kamera, LiDAR, radar).

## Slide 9

Prikaz arhitekture Jetson Thor modula


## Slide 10

Grace CPU + Blackwell GPU

- Napredni ARM Neoverse CPU
- Blackwell GPU ogromne paralelizacije
- Ugrađeni transformer engine i tensor cores kao AI akceleratori

Grace CPU obavlja napredne logičke i kontrolne zadatke, dok Blackwell GPU pruža ogromnu paralelizaciju za AI proračune. Integrisani Transformer Engine značajno ubrzava moderne modele zasnovane na transformatorima.

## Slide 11

Računarska moć

- Do 800 TOPS, obrada više od 10 senzora istovremeno
- Do 128 GB LPDDR5X, 256-bitni interfejs omogućava brz protok podataka između GPU, LLM i senzora
- Podesivi raspon energetske potrošnje za različite robote
- Masivna podrška za PCI Express, Ethernet i senzorske interfejse

Sa do 800+ TOPS i do 128 GB LPDDR5X memorije, Jetson Thor može obrađivati više senzora i kompleksne modele istovremeno. Visoka memorijska propusnost omogućava stabilan rad čak i kod najzahtjevnijih AI zadataka.

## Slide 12

KLJUČNE RAZLIKE

Thor vs Orin


Arhitektonski skok

Orin Ampere GPU zamijenjen je Blackwell GPU arhtitekturom koja nudi 3x više TOPS

Transformer engine

Najveća razlika je uvođenje namjenskog transformer engina, Thor je dizajniran da efikasno izvršava LLM kao što je ChatGPT

Orin revolucionaran za klasičnu robotiku

Dizajniran za klasičnu robotiku i umjetnu inteligenciju baziranu na konvolucijskim neuronskim mrežama (CNN)

Thor dizajniran za novu eru

Specifično dizajniran s ciljem unaprijeđenja generativne umjetne inteligencije

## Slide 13

KLJUČNE PREDNOSTI

Thor vs Orin

Specijalizovani transformer engine

Thor hardverski optimizovan za LLM-ove i multimodalne AI modele, dok Orin uopšte nema posvećene instrukcije za ove zadatke.

Nativna podrška za generativnu AI i multimodalne modele

Omogućava obradu teksta, slike i videa direktno na robotu bez potrebe za cloud-om.

Multi-Instance GPU (MIG)

Omogućava dijeljenje GPU-a na izolovane logičke instance. Ovo je ključno za sisteme koji moraju istovremeno pokretati zadatke različitih kritičnosti

FP8 i FP4 preciznosti

Omogućavaju mnogo brže izvršavanje velikih modela uz manju potrošnju memorije.

Osjetno veće AI performanse

Skok sa ~275 TOPS na ekvivalent od 800+ TOPS (FP8/FP4) omogućava obradu znatno kompleksnijih modela i većeg broja senzora u realnom vremenu.

Ogromna paralelna obrada

Idealno za humanoidne robote, autonomna vozila i industrijske sisteme sa desetinama senzora.

Povećana propusnost memorije

Smanjuje uska grla kod modela koji rade sa velikim tenzorima.

Dvostruko veća memorija

128 GB LPDDR5X čini Thor prvim Jetson modulom sposobnim za pokretanje velikih jezičkih modela direktno na uređaju.

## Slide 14

NEDOSTACI

Thor vs Orin

Visoka potrošnja energije

Zahtijeva 75–120 W za punu efikasnost, što ga cini neadekvatnim za male baterijske uređaje.

Znatno veći termalni zahtjevi

Potrebni su aktivno hlađenje, masivniji hladnjaci i stabilna napojna jedinica.

Viša cijena

Predstavlja veliku investiciju, posebno za manje projekte i startup-ove.

Hardverska nekompatibilnost unazad

zahtijeva nove carrier board-ove i napajanja, pa se ne može jednostavno ubaciti u postojeće Orin sisteme.

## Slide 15

PRIMJENA

Primjena Thor modula


Humanoidna robotika

Autonomna industrijska vozila

Zdravstvo, logistika i proizvodnja

Real-time multimodalna analiza

Jetson Thor je posebno dizajniran za humanoidne robote koji koriste vizualne i jezičke modele za interakciju s ljudima. Pored toga koristi se u autonomnim vozilima, industrijskim robotima, logističkim sistemima i naprednim AI aplikacijama.“

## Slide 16

KLJUČNE PRIMJENE

Fizički AI i robotika

Napredno prepoznavanje i fuzija senzora

Jetson Thor omogućava napredno prepoznavanje u robotici procesiranjem podataka sa više senzora (npr. kamere, LiDAR, IMU) u realnom vremenu. Ovo je ključno za zadatke kao što su 3D mapiranje, detekcija prepreka i razumijevanje okruženja.


Kontrola pokreta u realnom vremenu i autonomne akcije

U humanoidnim robotima, Jetson Thor pomaže u obradi podataka sa različitih izvora (kao što su kamere i senzori) i donosi odluke o pokretima, osiguravajući da roboti mogu interagirati sa ljudima i objektima na siguran i efikasan način. Thor pomaže u generiranju odgovora u realnom vremenu na ljudske geste ili promjene u okruženju, omogućavajući robotima da prilagode svoje pokrete i akcije u skladu s tim.


Podrška generativnom AI za složene zadatke

Humanoidni robot pokretan Jetson Thorom može istovremeno pokretati AI modele za prepoznavanje lica, prepoznavanje gestova i donosanje odluka, čineći robota sposobnim za interakcije u realnom vremenu, koje su svesne konteksta.

Integracija sa robotskim ekosistemom

Jetson Thor se besprijekorno integriše sa NVIDIA-ovom Isaac Robotics platformom, koja nudi kompletan skup alata za izgradnju, simulaciju i implementaciju robota sa AI moći.


Industrijske i autonomne robotske aplikacije

U industrijskim okruženjima, Jetson Thor se koristi za unapređenje sistema automatizacije, poput robotskih ruku, dronova i autonomnih vozila. Autonomni mobilni roboti (AMR) koriste Jetson Thor za planiranje puta i izbjegavanje prepreka, omogućavajući im da efikasno navigiraju kroz fabrike ili skladišta.

Robotika u industrijskoj automatizaciji

U industrijskom okruženju, Jetson Thor se može koristiti u robotskim rukama za zadatke kao što je kontrola kvaliteta, gdje se visoko-razlučive kamere i AI modeli koriste za identifikaciju nedostataka u realnom vremenu.

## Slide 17

PROJEKTOVANJE SISTEMA NA ČIPU

Hvala na pažnji!

Dženana Sadiković, Dženita Moranjkić, Mahir Suljić i Kešetović Amar

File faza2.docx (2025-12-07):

Specifikacija problema

Grupa 6

# Opis projekta

Tema projekta je automobil koji se kontroliše putem mobilne aplikacije. Automobil će imati 4 točka, kameru, 2 kočnice, parking senzore, zvučnu signalizaciju, LED svjetla, sposobnost detektovanja svjetla na semaforu, saobraćajnih znakova, prevenciju prelazka preko linije, itd.

Komunikacija između Raspberry Pi i FPGA će se odvijati putem digitalnih pin-ova. Svaki pin će biti zadužen za jednu od sljedećih akcija: kretanje naprijed, kretanje nazad, kretanje desno, kretanje lijevo, kočenje, zvučni signal.

Mobilna aplikacija će biti napisana u Kotlin programskom jeziku koristeći Android Studio i Jetpack Compose. Kamera se nalazi na prednjoj strani auta, a aplikacija će imati (near) real-time prikaz onoga što kamera automobila vidi. Sa jedne strane ekrana će biti komande za kretanje automobila, a sa druge strane će biti komande za kočenje i zvučnu singalizaciju. Komunikacija između mobilne aplikacije i Raspberry Pi će se odvijati putem HTTP protokola.

FPGA će preko drivera za motore (H mosta) kontrolisati motore koji su pričvešćeni za točkove. Jedan driver može pokretati dva motora, tako da će biti potrebna dva driver-a, jedan za lijevi par točkova, a drugi za desni par. Ovakav raspored će se koristiti jer je planirano korištenje diferencijalnog upravljanja, gdje za skretanje u desno, snaga lijevom paru točkova se poveća, a desnom paru točkova se smanji, i analogno za skretanje u lijevo.

Kada kamera detektuje crveno svjetlo na semaforu ili znak stop, Raspberry Pi će automatski poslati signal za kočenje. Ako ultrazvučni senzori detektuju da se automobil približio nekoj prepreci, FPGA će pomoću aktivnog piezo buzzer-a napraviti zvukove, slično kao parking senzor u autu. Prilikom kočenja, par crvenih LED koje se nalaze na zadnjoj strani auta će svijetliti sve dok je signal za kočenje aktivan. Kada se automobil „upali“, bijela svjetla na prednjoj strani automobila svijetle sve dok se automobil ne „ugasi“. Sa strana automobila će se nalaziti infracrveni senzori koji će detektovati linije. Ako senzor detektuje liniju, poslati će signal da automobil blago skrene u suprotnom smijeru i na taj način vrati unutar linija.

Odvojeno od glavnog projekta će biti jedan semafor. Semafor se sastoji od tri LED (crvena, žuta i zelena), koje će kontrolisati ESP-01S. Plan je da se simulira ponašanje pravog semafora, gdje se smjenjuju crvena i zelena boja, između kojih se pali žuta.

# Vizuelni prikaz modela


# Hardver sa tabelom ulaza i izlaza

Upravljačke ploča | | Slika


Raspberry Pi 4


Altera Cyclone 4 (FPGA)


ESP-01S
Ulazi | Upravljačka ploča | Namjena | Slika


Ultrasonični senzor (HC-SR04P) x2 | FPGA | Detekcija prepreka


Kamera (Logitech C512) | Raspberry PI | Detekcija znakova i video stream


Infracrveni senzor x2 | FPGA | Detekcija linija

Dodatno | Upravljačka ploča | Namjena | Slika


DC motor driver L298N x2 | FPGA | Kontrola motora


LED semafor | ESP-01S | Svjetlosna signalizacija

Izlazi | Upravljačka ploča | Namjena | Slika


DC motori x4 | FPGA | Kontrola kretanja


Servo motori x2 | FPGA | Kočnice


Aktivni piezo buzzer | FPGA | Zvučna singnalizacija


LED (nekoliko) | FPGA | Svjetlosna signalizacija

# Dijagram upravljanja


Raspberry Pi će uzimati video stream od kamere i pomoću AI detektovati koje je svjetlo upaljeno na semaforu, kao i STOP znak. Taj video stream će također slati na mobilnu aplikaciju. Mobilna aplikacija će slati kontrolne signale (kretanje, kočenje i zvučni signal) na Raspberry Pi koji će dalje te signale proslijediti do FPGA. FPGA će uzimati i procesirati signale sa Raspberry Pi, ultrasoničnih i infracrvenih senzora. Nakon procesiranja signala će slati kontrolne signale ostalim komponentama kao što su LED na autu, piezo buzzer, servo motore i DC motor driver koji će dalje pokretati DC motore na koje su pričvršćeni točkovi.

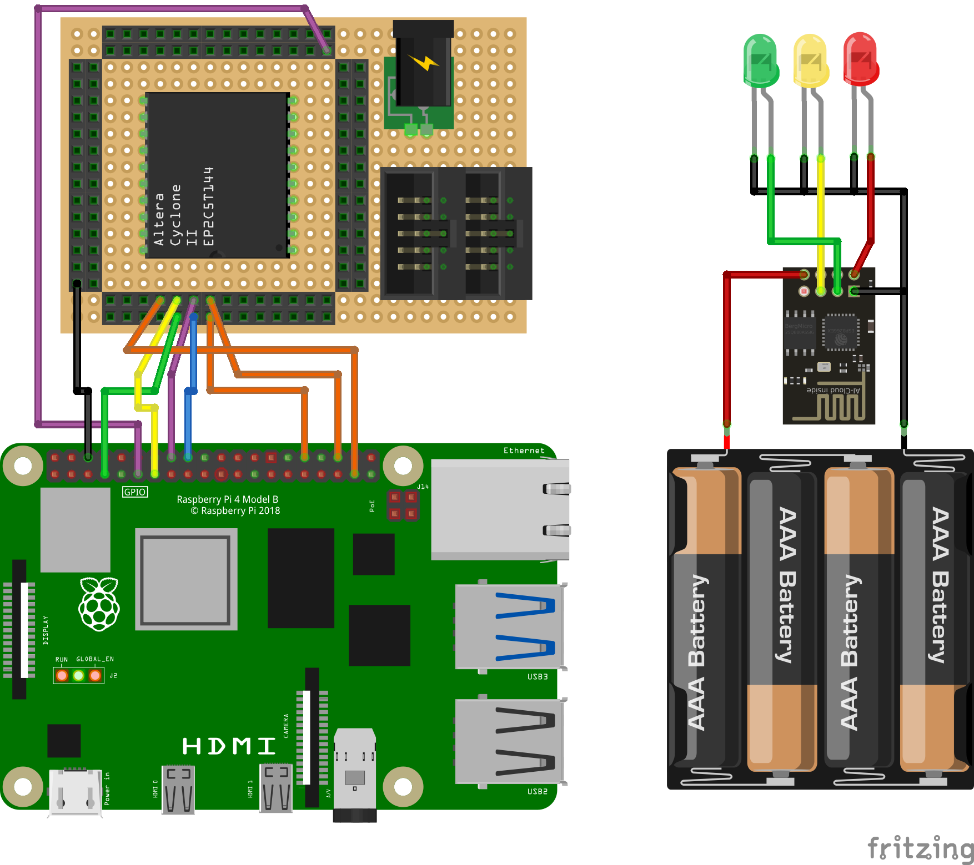
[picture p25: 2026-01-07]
slike/boards_schematic.png

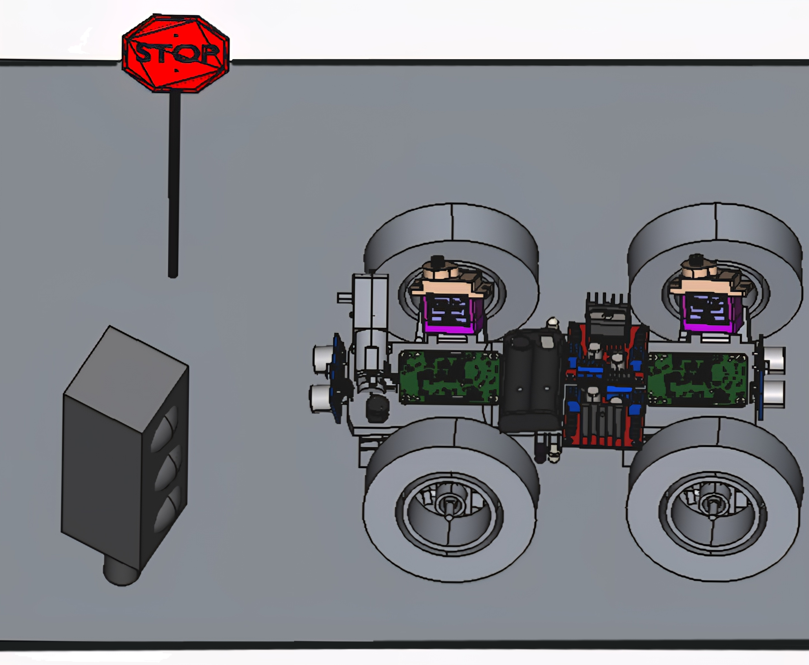
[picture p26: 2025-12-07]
model.png

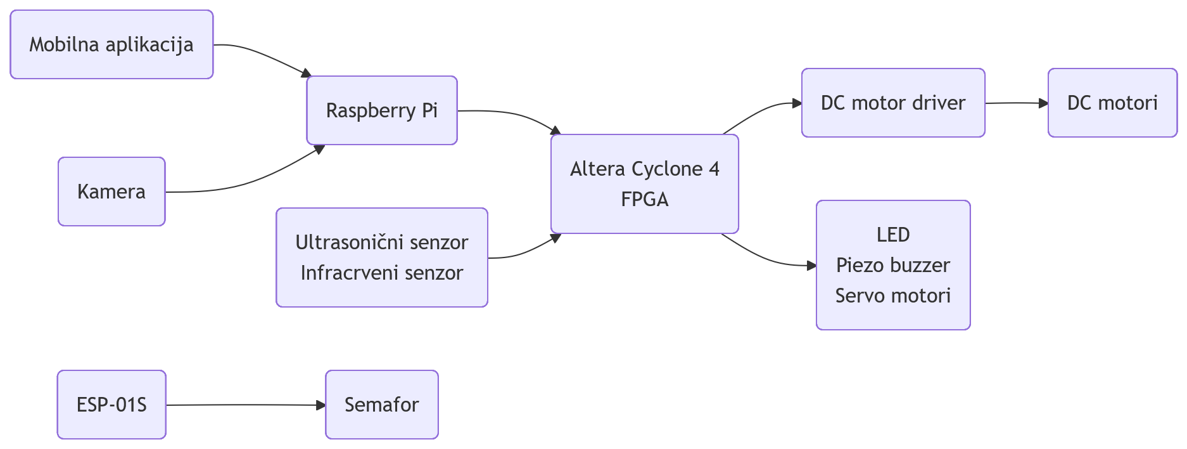
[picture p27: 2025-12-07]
graph.png

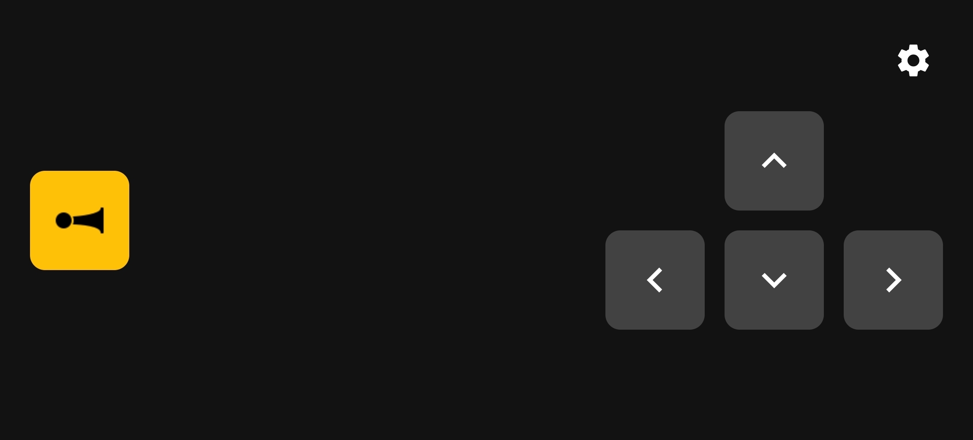
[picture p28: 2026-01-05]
slike/app_home.jpg

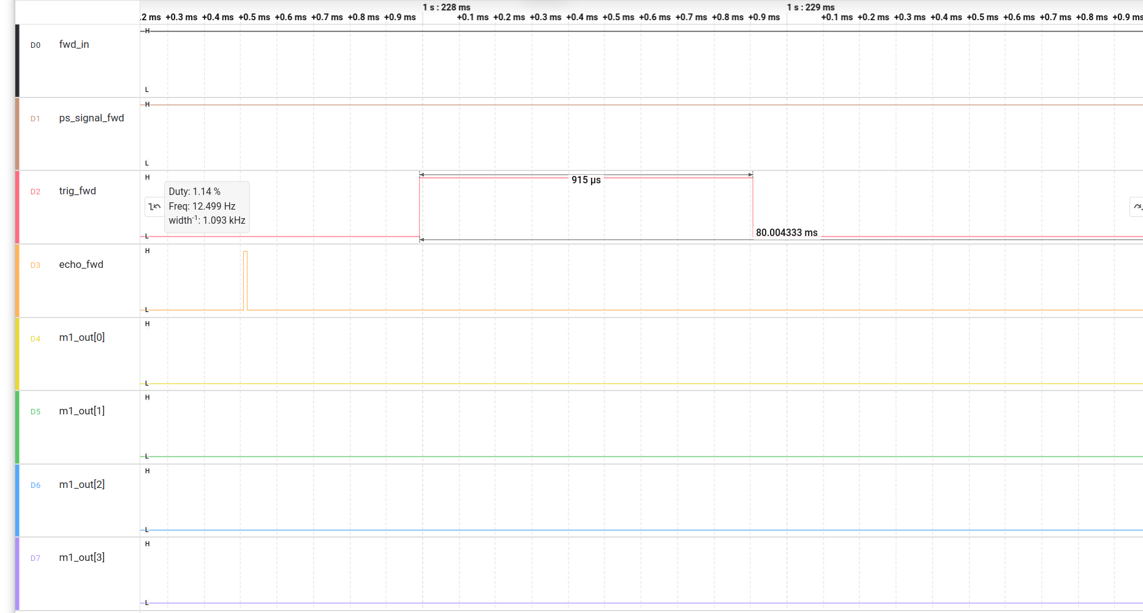
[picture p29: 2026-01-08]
slike/ultrasonic_2.png

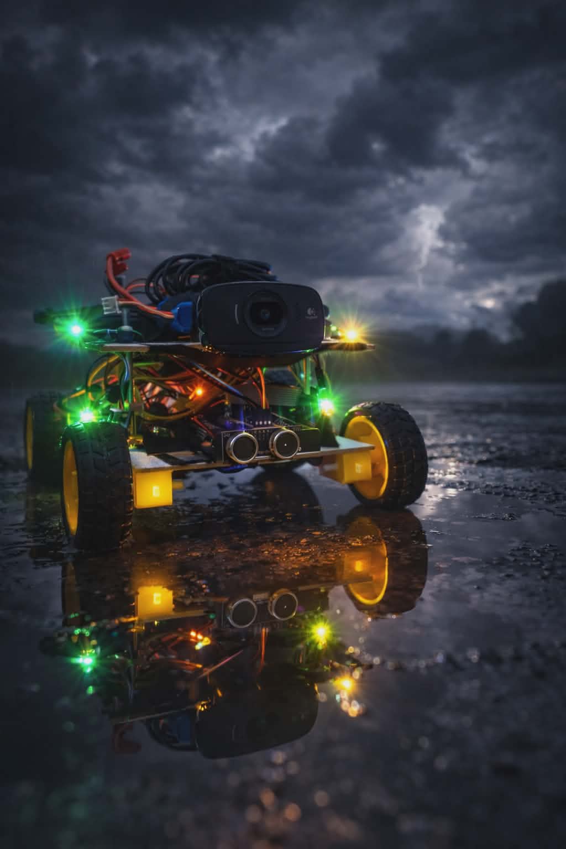
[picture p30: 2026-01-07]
slike/auto_ai.jpeg

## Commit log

2025-12-11 stop sign detection once, no more detection until car moved, added heartbeat that should be hit by kotlin periodically (failsafe if not)
    [detector.py, server.py]
2025-12-12 missed gpio setup for failsafe
    [detector.py, server.py]
2026-01-05 Added schematic
    [Car.fzz]
2026-01-07 Added board connection schematic
2026-01-08 Left Motor
2026-04-22 Heartbeat and reset seq update
    [server.py]
